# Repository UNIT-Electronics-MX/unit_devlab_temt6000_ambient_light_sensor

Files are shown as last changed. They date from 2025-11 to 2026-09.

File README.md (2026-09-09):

# DevLab: I2C TEMT6000 Ambient Light Sensor

The **DevLab I2C TEMT6000 Ambient Light Sensor** is a small ambient light sensor module that contains the **TEMT6000 phototransistor** and a **microcontroller**.This version has a **I2C interface** that allows the sensor signal to be captured, processed and accessed digitally from an I2C host, unlike a typical TEMT6000 module which only offers an analog output.

The module also includes a dedicated header for direct access to the **raw sensor signal** allowing the TEMT6000 output to be used directly for analog measurements, testing, characterization or custom signal processing. The board has three I2C connections, which makes it easy to integrate with other DevLab modules and I2C based systems.

<div align="center">

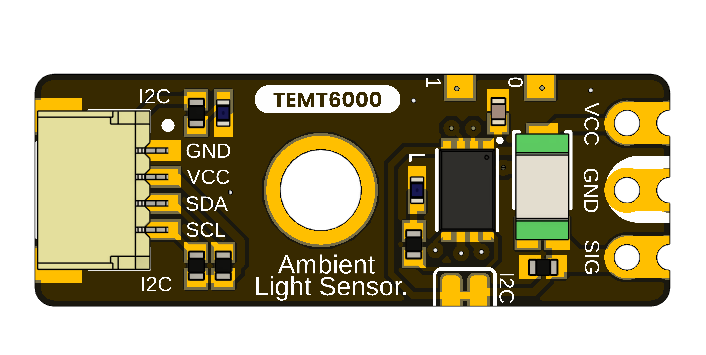
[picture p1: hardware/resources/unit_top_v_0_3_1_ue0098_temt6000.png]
DevLab I2C TEMT6000 Ambient Light Sensor
  

</div>

<div align="center">

### Quick Setup

[](https://wiki.uelectronics.com/wiki/devlab-temt6000-ambient-light-sensor)
[](https://github.com/UNIT-Electronics-MX/unit_devlab_temt6000_ambient_light_sensor/blob/main/hardware/unit_datasheet_v_1_0_0_ue0098_temt6000_ambient_light_sensor_en.pd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)
[](https://uelectronics.com/)
[](https://github.com/UNIT-Electronics-MX/unit_devlab_temt6000_ambient_light_sensor/tree/main/software)

</div>

## Overview

| Feature | Description |
|---|---|
| Sensor | TEMT6000 Ambient Light Sensor |
| Sensor Type | Ambient light phototransistor |
| Onboard MCU | 32-bit Arm Cortex-M0+ |
| Main Interface | I2C |
| Raw Signal Access | Direct sensor signal available through dedicated header |
| I2C Connectivity | 3 I2C connectors |
| Status Indicators | Power and user/status LEDs |
| Debug / Test | Dedicated test points |
| Module Function | Ambient light acquisition and I2C sensor interface |

## How It Works

The **TEMT6000** phototransistor generates a signal according to the incident ambient light level.

This signal is connected directly to the onboard **microcontroller**, which can acquire and process the sensor output and make the resulting information available through the **I2C interface**.

The board also exposes the sensor signal through the **RAW Signal Header**, allowing direct access to the unprocessed TEMT6000 output independently of the I2C interface.

This architecture provides two ways to work with the sensor:

- **I2C interface:** Easy digital integration with microcontrollers and other I2C systems.
- **RAW signal:** Direct access to the sensor output for analog measurements, testing, or custom processing.

## Use Cases

- Ambient light monitoring.
- Automatic display brightness adjustment.
- Smart lighting systems.
- Home and industrial automation.
- IoT environmental monitoring.
- Light-level data logging.
- Educational and prototyping applications.
- Sensor characterization using the RAW signal output.
- Integration into I2C sensor networks.

## Resources

- [Schematic Diagram](https://github.com/UNIT-Electronics-MX/unit_devlab_temt6000_ambient_light_sensor/blob/main/hardware/unit_sch_v_2_0_0_ue0098_temt6000.pdf)

- [Pinout Diagram](https://github.com/UNIT-Electronics-MX/unit_devlab_temt6000_ambient_light_sensor/blob/main/hardware/unit_pinout_v_0_0_2_ue0098_temt6000_ambient_light_sensor_en.pdf)

- [Datasheet](https://github.com/UNIT-Electronics-MX/unit_devlab_temt6000_ambient_light_sensor/blob/main/hardware/unit_datasheet_v_1_0_0_ue0098_temt6000_ambient_light_sensor_en.pd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)

## License

All hardware and documentation in this project are licensed under the **MIT License**.

Please refer to [`LICENSE.md`](LICENSE.md) for full terms.

<div align="center">

  <sub>Developed by UNIT Electronics</sub>

</div>

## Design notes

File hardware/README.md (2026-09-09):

# Hardware

<div align="center">

<a href="./unit_sch_v_2_0_0_ue0098_temt6000.pdf">
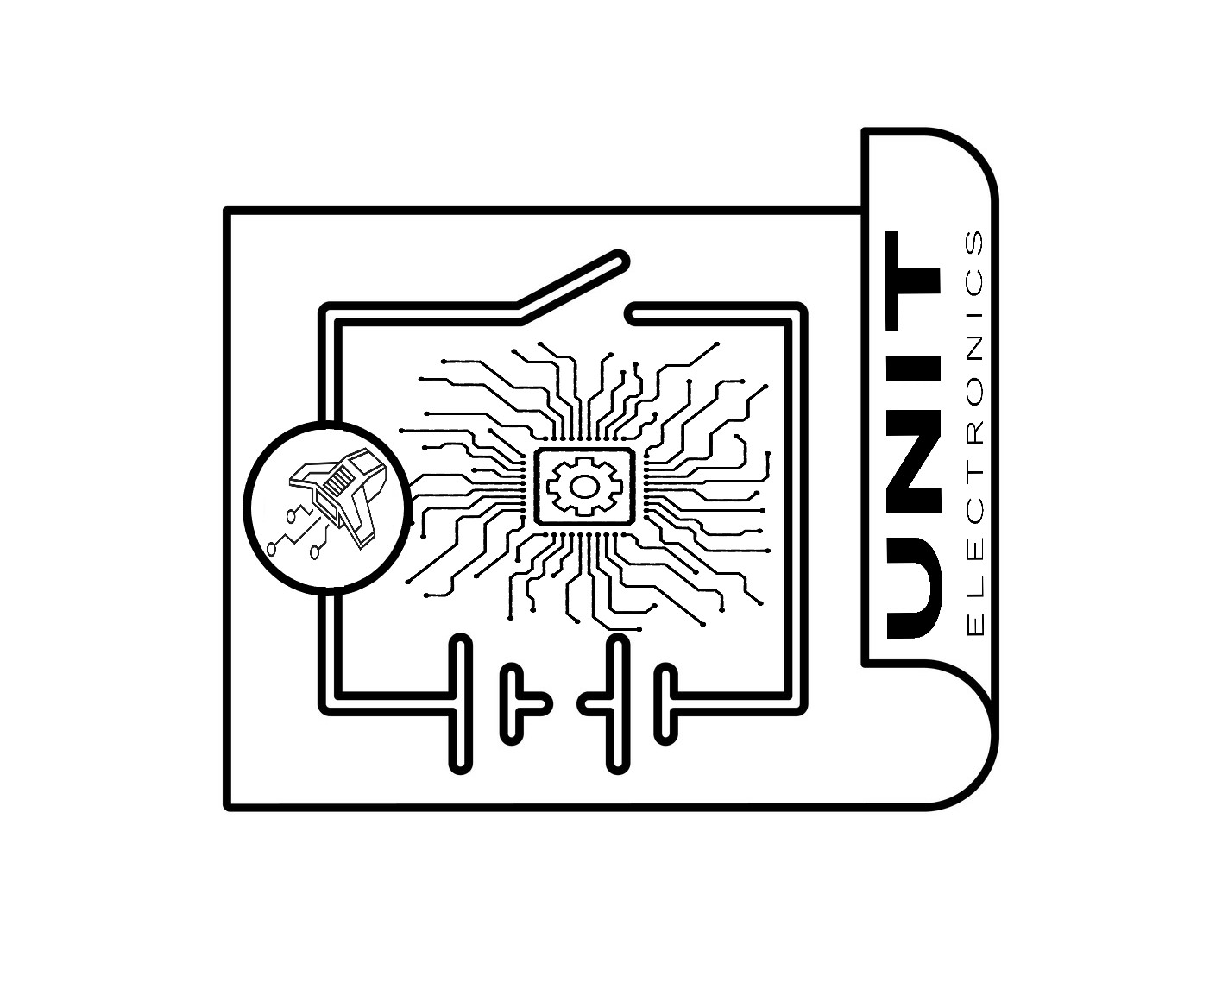
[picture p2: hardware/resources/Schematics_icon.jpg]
Schematics
  
  <br/>Schematics
</a>

</div>

---

## Key Technical Specifications

### Connectivity

<div align="center">

| Interface | Details |
|---|---|
| **Primary Interface** | I2C |
| **Sensor Interface** | TEMT6000 analog signal |
| **Raw Signal Access** | Dedicated RAW Signal Header |
| **I2C Connectors** | 3 × JST 4-pin, 1.0 mm pitch |
| **I2C Lines** | SDA, SCL |
| **Onboard MCU** | PY32F003L24D6TR |
| **I2C Pull-ups** | 10 kΩ |
| **Status Indicators** | Power LED and User LED |
| **Debug / Test** | Dedicated test points |

</div>

## Technical Specifications

The UE0098 integrates a **TEMT6000 ambient light sensor** with a
**microcontroller**, which acts as the interface between
the sensor signal and the I2C bus.

The TEMT6000 output is available for
signal acquisition and processing. The same sensor signal is also
exposed through a dedicated **RAW Signal Header**, allowing direct access
for measurement, testing, characterization, or external processing.

### I2C Interface

<div align="center">

| Signal | Type | Description |
|:---:|---|---|
| VCC | Power | Module power supply |
| GND | Power | Ground reference |
| SDA | I/O | I2C serial data |
| SCL | Input | I2C serial clock |

</div>

The board provides **three I2C connectors** connected to the same bus,
allowing convenient integration with other compatible I2C modules.

### RAW Signal Header

<div align="center">

| Signal | Type | Description |
|:---:|---|---|
| VCC | Power | Module supply voltage |
| GND | Power | Ground reference |
| SIGNAL | Analog | Direct TEMT6000 sensor signal |

</div>

> **Note:** The RAW Signal Header provides direct access to the TEMT6000
> sensor signal independently of the I2C interface.

## TEMT6000 Electrical Characteristics

The following characteristics correspond to the **TEMT6000 sensor**
itself and should not be interpreted as electrical limits for the
complete UE0098 module.

<div align="center">

| Symbol | Description | Min | Typ | Max | Unit |
|---|---|-----|-----|-----|---|
| V_CEO | Collector-emitter voltage | - | - | 6 | V |
| I_C | Collector current | - | - | 20 | mA |
| V_ECO | Emitter-collector voltage | - | - | 1.5 | V |
| P_V | Power dissipation | - | - | 100 | mW |
| φ | Angle of half sensitivity | - | ±60 | - | deg |
| λ_P | Wavelength of peak sensitivity | - | 570 | - | nm |
| λ_0.5 | Spectral bandwidth range | 440 | - | 800 | nm |

</div>

> **Note:** Refer to the Vishay TEMT6000 datasheet for complete sensor
> electrical and optical characteristics.

## Pinout

<div align="center">

<a href="./unit_pinout_v_3_1_0_ue0098_temt6000_ambient_light_sensor_en.pdf">
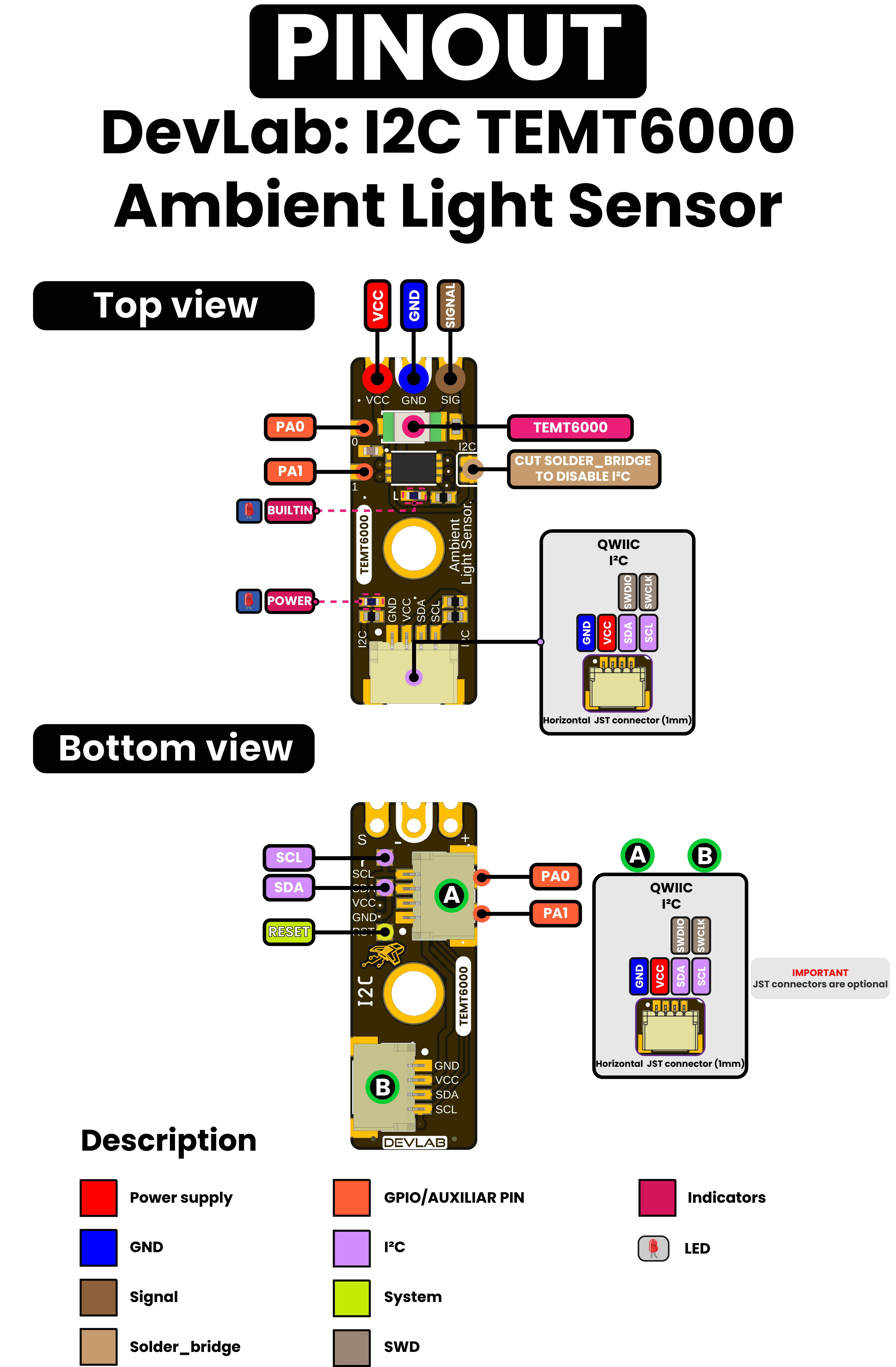
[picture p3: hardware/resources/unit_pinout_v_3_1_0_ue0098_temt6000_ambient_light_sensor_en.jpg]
  
  <br/>Pinout
</a>

<br/><br/>

</div>

### Pinout Details

#### I2C Connectors

<div align="center">

| Pin Label | Function | Description |
|---|---|---|
| VCC | Power Supply | Module power supply |
| GND | Ground | Common ground reference |
| SDA | I2C Data | Serial data line |
| SCL | I2C Clock | Serial clock line |

</div>

#### RAW Signal Header

<div align="center">

| Pin Label | Function | Description |
|---|---|---|
| VCC | Power Supply | Module power supply |
| GND | Ground | Common ground reference |
| SIGNAL | Raw Sensor Signal | Direct TEMT6000 output signal |

</div>

## Topology

<div align="center">

<a href="./resources/unit_topology_v_3_1_0_ue0098_temt6000_ambient_light_sensor.png">
  
  <br/>Topology
</a>

| Ref. | Description |
|---|---|
| TEMT6000 | Ambient Light Sensor |
| IC1 | PY32F003L24D6TR I2C Driver / |
| J1, J3, J4 | I2C JST 4-pin, 1.0 mm pitch connectors |
| J2 | RAW Signal Header |
| PWR | Power status LED |
| USR_LED | User / status LED |
| TP | Test points |

</div>

## Hardware Architecture

The module uses the following signal architecture:

**TEMT6000 → Raw Sensor Signal → microcontroller → I2C**

The TEMT6000 generates an analog signal according to the incident light
level. This signal is acquired by the onboard PY32F003,
which can process the sensor information and expose it through the I2C
interface.

In parallel, the unprocessed sensor signal remains available through the
**RAW Signal Header**:

**TEMT6000 → RAW Signal Header**

This architecture allows the module to be used both as an I2C ambient
light sensor and as a platform for direct access to the TEMT6000 signal.

## Dimensions

<div align="center">

<a href="./resources/unit_dimensions_v_3_1_0_ue0098_temt6000_ambient_light_sensor.png">
  
  <br/>Dimensions
</a>

</div>

## Reference

- [TEMT6000 Datasheet](https://www.vishay.com/docs/84374/temt6000.pdf)

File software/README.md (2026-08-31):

# Using the UNIT ATOM TEMT6000

UNIT Electronics creates and develops the DevLab board ecosystem, and this
product belongs to its Atom family. Hardware V0.3.1 provides two development
paths: Qwiic I2C through its onboard PY32F003 controller and direct analog observation
through `SIG`.

## I2C bring-up

Use a current-limited 3.3 V or 5 V supply and connect `GND`, `VCC`, `SDA`, and
`SCL` in the released pinout orientation. At 5 V, the host must tolerate the
actual I2C pull-up voltage or use a level shifter. Use 7-bit addressing and an I2C clock
from 100 kHz through 400 kHz. The repository includes low-level bus scanners:

The normal function of `PA10`/`PB6` is `SDA`/`SCL`. Their factory-only
`SWDIO`/`SWCLK` functions use the same physical pins, not a separate port, and
must never be driven while the I2C bus is active.

- [`examples/i2c/cpp_examples/i2c_scanner/i2c_scanner.ino`](examples/i2c/cpp_examples/i2c_scanner/i2c_scanner.ino)
  for C++ with the Arduino framework;
- [`examples/i2c/micropython/i2c_scan.py`](examples/i2c/micropython/i2c_scan.py) for
  MicroPython.

It also includes DDP measurement clients:

- [`examples/i2c/cpp_examples/ddp_temt6000/ddp_temt6000.ino`](examples/i2c/cpp_examples/ddp_temt6000/ddp_temt6000.ino)
  for C++ with the Arduino framework, using the canonical
  [`DevLabDDP`](https://github.com/UNIT-Electronics-Labs/unit_devlab_ddp_library)
  library;
- [`examples/i2c/micropython/ddp_temt6000.py`](examples/i2c/micropython/ddp_temt6000.py)
  for MicroPython, using the reusable
  [`devlab_ddp.py`](examples/i2c/micropython/lib/devlab_ddp.py) module.

The example tree is separated by interface (`i2c` or `adc`) and then by
language. See [`examples/README.md`](examples/README.md) for the selected
end-user examples and dependencies.

Both clients start with factory address `0x20`, can scan valid 7-bit addresses,
execute the mandatory DDP discovery sequence, accept only Device ID `0x0102`,
inspect capabilities at runtime, and then read the TEMT6000 sample. The command
is `TEMT6000_RAW` (`0x80`),
which returns a 12-bit ADC code (`0` to `4095`) in an unsigned 16-bit
little-endian response. The same published `PA2` sample is available through
common `READ_ADC0` (`0x60`).

The controller publishes an internally averaged ADC value approximately every 20 ms.
The persistent averaging window accepts 1, 4, 8, 16, or 24 samples; clients
read the current value before writing it. DDP address commands `0x20..0x24`
report, change, restore, and describe the active 7-bit address. Address and
averaging mutation are disabled by default in the examples.

`PB5/BUILTIN` uses `RELAY_OFF/ON/TOGGLE` (`0xA0..0xA2`), not the unsupported
digital-output commands. See [`protocol/README.md`](protocol/README.md) for the
exact controller command profile, staged acknowledgements, timing, and limitations.

For MicroPython installation and API details, see
[`examples/i2c/micropython/README.md`](examples/i2c/micropython/README.md). Copy
`devlab_ddp.py` to the host's `/lib` directory before running the DDP example.
The repository's ESP32 and MicroPython I2C examples use GPIO6 for SDA and GPIO7
for SCL.

## Direct analog bring-up

Connect the direct contacts while unpowered:

| Module | Host | Note |
|---|---|---|
| `GND` | Ground | Common reference |
| `VCC` | Module supply | 3.3 V or 5 V nominal; controller upper operating limit is 5.5 V |
| `SIG` | High-impedance ADC input | Signal is referenced to `VCC`; verify range before connecting a lower-voltage ADC |

- [`examples/adc/cpp_examples/light_sensor/light_sensor.ino`](examples/adc/cpp_examples/light_sensor/light_sensor.ino)
  reports averaged
  ADC code and voltage.
- [`examples/adc/micropython/light_sensor.py`](examples/adc/micropython/light_sensor.py)
  adds averaging and voltage conversion.

Set the ADC pin, resolution, and full-scale voltage for the host. The examples
do not convert to lux because the only schematic in the repository applies to
legacy V0.0.1 hardware; the V0.3.1 analog transfer needs release and validation.

## I2C disable bridge

Do not cut the bridge as a first troubleshooting step. Verify power, connector
orientation, SDA/SCL continuity, pull-ups, and bus ownership first. If the
current assembly must be isolated for analog-only testing, remove power and
document/inspect the rework carefully.

## Troubleshooting

| Symptom | Check |
|---|---|
| No I2C address | Supply and bus-logic compatibility, ground, connector population/orientation, SDA/SCL, intact bridge |
| Bus held low | Cable reversal, unpowered device, pull-ups, or unintended external drive on shared service lines |
| Address found but rejected | Confirm DDP protocol major 1 and Device ID `0x0102`; check for another device at that address |
| DDP device found but read fails | Confirm `ANALOG_INPUT`/`SENSOR_DATA`, 5 ms processing delay, exact response length, and command/STOP/read sequence |
| Analog always zero/full scale | ADC pin/range, supply, optical path, current-board transfer |
| Noisy analog value | Cable length, averaging, acquisition time, reference and supply noise |

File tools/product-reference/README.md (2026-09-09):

# Product Reference build

The UNIT ATOM TEMT6000 Product Reference source is maintained in Markdown under
`chapters/`. Document metadata and chapter order are defined in `book.yml`.
Version 1.1.0 is based on the V0.3.1 board images, V3.1.0 pinout, topology and
dimensions, current V2.0.0 schematic, a Vishay TEMT6000X01 datasheet used only
as a comparative reference, DevLab Device Protocol v1.0, and the repository
examples. The reference datasheet does not establish the exact orderable part
fitted to the module.

The Product Reference documents the current PY32F003 firmware profile: factory
address `0x20`, internal HSI operation at up to 24 MHz without an external
oscillator, DDP identity `0x0102`, versions 1.0, capabilities
`0x000001B9`, command timing, persistent configuration, ADC averaging, and the
`TEMT6000_RAW` (`0x80`) 12-bit response. It keeps the current-revision
schematic and complete module electrical limits as open qualification
requirements.

## Local validation build

Requirements:

- Pandoc
- WeasyPrint, Google Chrome, or Chromium

Run from the repository root and direct validation output outside the
repository:

```bash
./tools/product-reference/build.sh /tmp/atom-temt6000-product-reference
```

The build produces:

```text
unit_product_reference_v_1_1_0_atom_temt6000_ambient_light_sensor.md
unit_product_reference_v_1_1_0_atom_temt6000_ambient_light_sensor.docx
unit_product_reference_v_1_1_0_atom_temt6000_ambient_light_sensor.html
unit_product_reference_v_1_1_0_atom_temt6000_ambient_light_sensor.pdf
```

GitHub Actions publishes the PDF and DOCX under `docs/hardware/`. Do not edit
generated documents or `docs/` manually.

The Markdown chapters are the source of truth. Module values and mappings must
come from controlled technical references. The V0.3.1 module provides three
I2C connection positions on the same bus—one populated by default and two
optional horizontal positions—plus separate direct analog access through the
`VCC`/`GND`/`SIG` header. Do not infer complete-module limits from a component
rating alone.

Known source inconsistencies and unspecified board-level values are listed in
Chapter 9.

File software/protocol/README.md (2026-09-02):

# UNIT ATOM TEMT6000 — controller DDP device profile

UNIT Electronics creates and develops the DevLab board ecosystem; this product
belongs to its Atom family. Hardware V0.3.1 communicates through **DevLab
Device Protocol (DDP) v1.0** over I2C. This profile describes the observable
behavior of the current controller firmware. Common command values come from the canonical
[`unit_devlab_ddp_library`](https://github.com/UNIT-Electronics-Labs/unit_devlab_ddp_library).

Repository implementations are the Arduino `DevLabDDP` client and the reusable
MicroPython [`devlab_ddp.py`](../examples/i2c/micropython/lib/devlab_ddp.py) module. Both use the
same command/STOP/read transaction model and identity sequence.

## Released runtime profile

| Field | Current value |
|---|---|
| DDP Device ID | `0x0102` (little-endian bytes `[0x02, 0x01]`) |
| Protocol version | 1.0 (major/minor bytes `[0x01, 0x00]`) |
| Firmware version | 1.0 (major/minor bytes `[0x01, 0x00]`) |
| Hardware version | 1.0 (major/minor bytes `[0x01, 0x00]`) |
| Capabilities | `0x000001B9` (little-endian bytes `[0xB9, 0x01, 0x00, 0x00]`) |
| Factory 7-bit address | `0x20` |
| Configurable address range | `0x08..0x77` |
| I2C clock | 100 kHz to 400 kHz; examples use 400 kHz |
| Controller | PY32F003, 32-bit Arm Cortex-M0+; 16 KB Flash, 2 KB SRAM; internal HSI at up to 24 MHz for this application; no external HSE oscillator |
| Controller supply-voltage guidance | 2.0–5.5 V; conservative range used until the exact fitted variant is confirmed |
| Controller bus pins | `PB6/SCL`, `PA10/SDA` |
| Command/parameter size | One byte per write transaction |
| Maximum prepared response | Four bytes |
| Processing delay before read | 2–5 ms; use 5 ms conservatively |
| Pending setter timeout | 250 ms |
| ADC format | 12-bit unsigned, `0..4095`, little-endian `uint16` |

The capability bitmap announces `I2C_CONFIG`, `ANALOG_INPUT`, `SENSOR_DATA`,
`RELAY`, `WATCHDOG`, and `PERSISTENT_CONFIG`. It does not announce digital I/O;
commands `READ_GPIO0/1` (`0x40/0x41`) and `WRITE_GPIO0/1` (`0x42/0x43`) are not
implemented.

### Meaning of byte `0x01`

`0x01` has no universal meaning in DDP; its meaning comes from the command,
response length, and field encoding. In this profile:

- as a command byte, `0x01` selects `GET_FIRMWARE_VERSION`;
- in version bytes `[0x01, 0x00]`, it is major version 1;
- in Device ID bytes `[0x02, 0x01]`, it is the high byte of little-endian
  `0x0102`;
- in capability bytes `[0xB9, 0x01, 0x00, 0x00]`, it is byte 1 of the
  little-endian bitmap `0x000001B9`;
- as the low nibble of a `RELAY_ON` acknowledgement, `0x1` means that driving
  `PB5/BUILTIN` HIGH was accepted; and
- as the `GET_I2C_STATUS` response, `0x01` means the active address was loaded
  from Flash.

Never interpret an isolated `0x01` without first identifying its command and
expected response format.

## Logical and physical mapping

| Logical resource | Physical resource | Implemented command |
|---|---|---|
| `ADC0` | TEMT6000 sampled on controller `PA2` | `READ_ADC0` (`0x60`) |
| TEMT6000 sensor data | Same published ADC sample | `TEMT6000_RAW` (`0x80`) |
| Relay-compatible actuator | Controller `PB5` / `BUILTIN` | `RELAY_OFF/ON/TOGGLE` (`0xA0..0xA2`) |
| `PA0`, `PA1` | Exposed reserved pads | No current application assignment |

`READ_ADC0` and `TEMT6000_RAW` return the same most recently published
sample. An I2C read does not start an ADC conversion. The historical `RELAY_*`
names control `PB5` and therefore the `BUILTIN` indicator on this product.

## I2C transaction model

This is a command protocol, not a memory-mapped register interface. A normal
read requires a STOP between command and response:

```text
host -> [SLA+W, command] -> STOP
wait 2..5 ms
host -> [SLA+R, exact documented response length] -> NACK + STOP
```

Do not send a command and its parameter in one write. Setters use two explicit
stages and packed compatibility acknowledgements:

```text
host -> [SLA+W, command] -> STOP
wait, then read one-byte initial ACK
host -> [SLA+W, value] -> STOP       (within 250 ms)
wait, then read one-byte final ACK
```

Validate the documented low nibble of each staged-operation acknowledgement;
never mask ADC data, addresses, versions, or averaging values. If a read is too
early or too long, transport padding can be `0xFF`, so clients must validate
length, identity, and value range.

## Mandatory discovery

| Order | Command | Value | Exact current response |
|---:|---|---:|---|
| 1 | `GET_PROTOCOL` | `0x04` | `[0x01, 0x00]` = major 1, minor 0 |
| 2 | `GET_DEVICE_ID` | `0x00` | `[0x02, 0x01]` = little-endian `0x0102` |
| 3 | `GET_FIRMWARE_VERSION` | `0x01` | `[0x01, 0x00]` = major 1, minor 0 |
| 4 | `GET_HARDWARE_VERSION` | `0x02` | `[0x01, 0x00]` = major 1, minor 0 |
| 5 | `GET_CAPABILITIES` | `0x03` | `[0xB9, 0x01, 0x00, 0x00]` = little-endian `0x000001B9` |

Cache identity after `begin()` rather than repeating all five reads before
every sample. Repeat discovery after reset, address change, or bus recovery.

## Implemented application commands

| Command | Code | Response/effect |
|---|---:|---|
| `READ_ADC0` | `0x60` | ADC `[LSB, MSB]` |
| `SET_ADC_AVERAGING` | `0x62` | Staged write; ACK low nibble `0xC` |
| `GET_ADC_AVERAGING` | `0x63` | `1`, `4`, `8`, `16`, or `24` |
| `TEMT6000_RAW` | `0x80` | Same ADC `[LSB, MSB]` as `0x60` |
| `RELAY_OFF` | `0xA0` | ACK low `0x0`; drives `PB5` low |
| `RELAY_ON` | `0xA1` | ACK low nibble `0x1` = `PB5` HIGH accepted |
| `RELAY_TOGGLE` | `0xA2` | ACK low `0x6`; non-blocking pulse |
| `SET_TOGGLE_TIME` | `0xA3` | Staged write `1..40`; ACK low `0x7` |
| `GET_TOGGLE_TIME` | `0xA4` | `1..40`, in units of 25 ms |

`READ_GPIO0/1`, `WRITE_GPIO0/1`, and `READ_ADC1` are not implemented and
return the packed unknown-command code with low nibble `0xB`.

## ADC acquisition and averaging

The controller updates its ADC sample in the background approximately every 20 ms
(about 50 samples/s). For each update it discards one conversion to settle the
sample-and-hold, takes one 12-bit conversion, updates a circular buffer, and
publishes `round(sum / valid_samples)`.

| Samples | Window | Fill time after change | Typical use |
|---:|---:|---:|---|
| 1 | 20 ms | 20 ms | Fast response |
| 4 | 80 ms | 80 ms | Low-latency control |
| 8 | 160 ms | 160 ms | UI and general automation |
| 16 | 320 ms | 320 ms | Stable ambient measurement |
| 24 | 480 ms | 480 ms | Maximum stability |

The factory averaging value is 1. `SET_ADC_AVERAGING` persists the selected
value in Flash, so read `GET_ADC_AVERAGING` first and write only when it needs
to change. Wait `N × 20 ms` for a fully refilled window. Do not poll faster than
20 ms expecting a new sample, and do not describe the raw average as lux.

## Address management

| Command | Code | Current behavior |
|---|---:|---|
| `GET_I2C_ADDR` | `0x20` | Active 7-bit address |
| `SET_I2C_ADDR` | `0x21` | Staged value `0x08..0x77`; ACK low `0xD`; saves Flash and resets automatically |
| `SAVE_CONFIG` | `0x22` | Returns `00`; idempotent because setters already persist |
| `RESET_FACTORY` | `0x23` | ACK low `0xE`; reset still required |
| `GET_I2C_STATUS` | `0x24` | `0x00` = factory/default; `0x01` = address loaded from Flash |

Before an address change, verify that the target is free. Read the initial ACK,
write the new value within 250 ms, wait about 100 ms for Flash, read the final
ACK at the old address, wait about 300 ms for reset, then verify protocol 1.x
and Device ID `0x0102` at the new address. If the final ACK is lost, probe the
new address once and then the old address rather than rewriting indefinitely.

Factory restoration keeps the old address active until reset:

```text
old: RESET_FACTORY (0x23) -> ACK low 0xE
old: RESET (0xF0) -> do not request a response
wait 300 ms
identify factory address 0x20
```

## Built-in indicator

`PB5/BUILTIN` uses the relay-compatible actuator block, not digital GPIO
output commands. A client can blink using `RELAY_ON`/`RELAY_OFF` with host
timing, or request a non-blocking pulse with `RELAY_TOGGLE`. Toggle time accepts
`1..40` units of 25 ms (25–1000 ms) and is persistent.

## Current firmware limitations

- `WATCHDOG` is announced, but `WATCHDOG_RESET` does not use an active hardware
  IWDG and must remain experimental/disabled by default.
- `GET_RESET_INFO` is not implemented; NRST support is incomplete.
- The internal error sentinel can appear as `0x0FFF`, indistinguishable from a
  legitimate full-scale ADC sample.
- Bus-BUSY recovery exists in firmware but is not called by the current main
  loop.
- There is no timestamp, sample counter, or calibrated lux output.
- The V0.3.1 schematic and complete module electrical limits remain pending.

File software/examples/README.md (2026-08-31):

# UNIT ATOM TEMT6000 examples

Choose the interface first. The `i2c/` examples use the module's DDP firmware;
the `adc/` examples read the separate direct `SIG` contact. They are kept in
different trees so wiring and host-pin assumptions are not mixed.

## Layout

```text
examples/
├── i2c/
│   ├── cpp_examples/
│   │   ├── ddp_temt6000/       normal DDP measurement client
│   │   └── i2c_scanner/        bus troubleshooting only
│   └── micropython/
│       ├── lib/devlab_ddp.py   reusable library; copy to the board's /lib
│       ├── ddp_temt6000.py     normal DDP measurement client
│       └── i2c_scan.py         bus troubleshooting only
└── adc/
    ├── cpp_examples/
    │   └── light_sensor/       direct SIG reading
    └── micropython/
        └── light_sensor.py     averaged direct SIG reading
```

## I2C — recommended interface

Start with `ddp_temt6000` for normal operation. Use `i2c_scanner` or
`i2c_scan.py` only when the module is not discovered.

| Language | Normal example | Diagnostic example |
|---|---|---|
| C++/Arduino framework | [`i2c/cpp_examples/ddp_temt6000`](i2c/cpp_examples/ddp_temt6000/ddp_temt6000.ino) | [`i2c/cpp_examples/i2c_scanner`](i2c/cpp_examples/i2c_scanner/i2c_scanner.ino) |
| MicroPython | [`i2c/micropython/ddp_temt6000.py`](i2c/micropython/ddp_temt6000.py) | [`i2c/micropython/i2c_scan.py`](i2c/micropython/i2c_scan.py) |

The ESP32 and MicroPython I2C examples use host GPIO6 for SDA and GPIO7 for
SCL. Generic Arduino targets fall back to the board's default `Wire` pins.
These are host pins, not the module's internal controller pins.

The C++ client requires the canonical
[`DevLabDDP`](https://github.com/UNIT-Electronics-Labs/unit_devlab_ddp_library)
library. For MicroPython, install
[`i2c/micropython/lib/devlab_ddp.py`](i2c/micropython/lib/devlab_ddp.py) in the
device's `/lib` directory; see the
[`i2c/micropython` guide](i2c/micropython/README.md).

## ADC — direct SIG only

Use this path only when the host is wired to the direct `SIG` contact instead
of using the DDP measurement client.

| Language | Example |
|---|---|
| C++/Arduino framework | [`adc/cpp_examples/light_sensor`](adc/cpp_examples/light_sensor/light_sensor.ino) |
| MicroPython | [`adc/micropython/light_sensor.py`](adc/micropython/light_sensor.py) |

Set the ADC-capable host pin and full-scale voltage for the selected board.
The examples report ADC code and voltage, not lux, because the V0.3.1 analog
transfer function still requires release and validation.

## Electrical note

The module supports nominal 3.3 V or 5 V operation. At 5 V, the host must
tolerate the actual I2C pull-up level or use a bidirectional level shifter.
`SDA/SCL` share their physical controller pins with the factory-only
`SWDIO/SWCLK` functions; user examples use I2C only.

See [`../protocol/README.md`](../protocol/README.md) for command timing,
response formats, capabilities, and address-change behavior.

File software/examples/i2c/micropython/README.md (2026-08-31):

# DevLab DDP for MicroPython

[`lib/devlab_ddp.py`](lib/devlab_ddp.py) is a reusable MicroPython master for DevLab
Device Protocol 1.0 over I2C. It mirrors the canonical Arduino transport rules:

- one command byte followed by STOP;
- a configurable processing delay before the response read;
- exact response lengths;
- little-endian decoding for Device ID, capabilities, and ADC data;
- mandatory protocol-major validation;
- Device ID discovery and matching;
- staged one-byte setters with packed acknowledgement validation; and
- collision-safe persistent I2C address changes.

## Install on a MicroPython board

Create `/lib` if it does not exist, then copy the module and example with
`mpremote`:

```bash
mpremote fs mkdir :/lib
mpremote fs cp software/examples/i2c/micropython/lib/devlab_ddp.py :/lib/devlab_ddp.py
mpremote fs cp software/examples/i2c/micropython/ddp_temt6000.py :/ddp_temt6000.py
```

The included I2C examples default to host GPIO6 for SDA and GPIO7 for SCL.
Edit `I2C_BUS`, `SDA_PIN`, and `SCL_PIN` only when the host board requires a
different mapping, then run:

```bash
mpremote run software/examples/i2c/micropython/ddp_temt6000.py
```

The module uses only the standard `machine.I2C` API. The host port must provide
`scan()`, `writeto()`, and `readfrom()` with STOP support.

## Minimal use

```python
from machine import I2C, Pin
from devlab_ddp import DEVICE_TEMT6000, Master, format_device_info

i2c = I2C(0, sda=Pin(6), scl=Pin(7), freq=400_000)
ddp = Master(i2c, expected_device_id=DEVICE_TEMT6000)
info = ddp.discover(preferred_address=0x20)

if info is None:
    raise OSError("TEMT6000 DDP device not found")

print(format_device_info(info, DEVICE_TEMT6000))
print(ddp.read_adc(info.address, channel=0, verify=False))
```

After discovery, `verify=False` avoids repeating the five identity reads before
every sample. Repeat discovery after reset, address change, or bus recovery.

## Main API

| Method | Purpose |
|---|---|
| `identify(address)` | Read protocol, Device ID, versions, and capabilities |
| `discover(preferred_address=None)` | Find the expected DDP device on the bus |
| `scan_ddp()` | Return every valid DDP device found |
| `read_command(address, command, length)` | Execute the DDP command/STOP/read transaction |
| `read_adc(address, channel)` | Read generic ADC0 or ADC1 |
| `read_gpio(address, channel)` | Read logical GPIO0 or GPIO1 |
| `get_adc_averaging(address)` | Read the persistent averaging window |
| `set_adc_averaging(address, samples)` | Apply a validated staged averaging write |
| `get_i2c_address(address)` | Read the active 7-bit address |
| `set_i2c_address(old, new)` | Check collision, persist the address, and rediscover |
| `relay_off/on/toggle(address)` | Execute the relay-compatible actuator commands |
| `set_toggle_time(address, units)` | Set `1..40` units of 25 ms |

Protocol constants, capability bits, Device IDs, response codes, exception
types, little-endian helpers, and `DeviceInfo` are exported by the module.

## Host-side tests

The tests use a scripted fake I2C bus and do not require hardware:

```bash
python3 -m unittest software/tests/test_devlab_ddp.py
```

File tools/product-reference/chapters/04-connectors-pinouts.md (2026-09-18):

## **4 Connectors & Pinouts**

The user-accessible interfaces are described below by module function. The
released documentation does not provide controlled contact numbers or a
mating-connector part number, so the signal order must be checked against the
connector orientation before producing a harness.

### **4.1 General Pinout** {.section-page}

| Connection group | Signals | Function |
|---|---|---|
| Direct sensor contacts | `VCC`, `GND`, `SIG` | Module power and direct access to the TEMT6000 analog signal |
| I2C connection positions | `GND`, `VCC`, `SDA`, `SCL` | Power and digital communication over the common I2C bus |
| Reserved expansion pads | Reserved | No current application assignment; electrical limits are not specified |

The PCB has three physical I2C connection positions. One connector is
populated by default, and two additional horizontal positions accept optional
4-pin, 1.00 mm-pitch JST/Qwiic-compatible connectors. All three positions are
connected to the same I2C bus.

### **4.2 Signal and I2C Connection Guide** {.page-break}

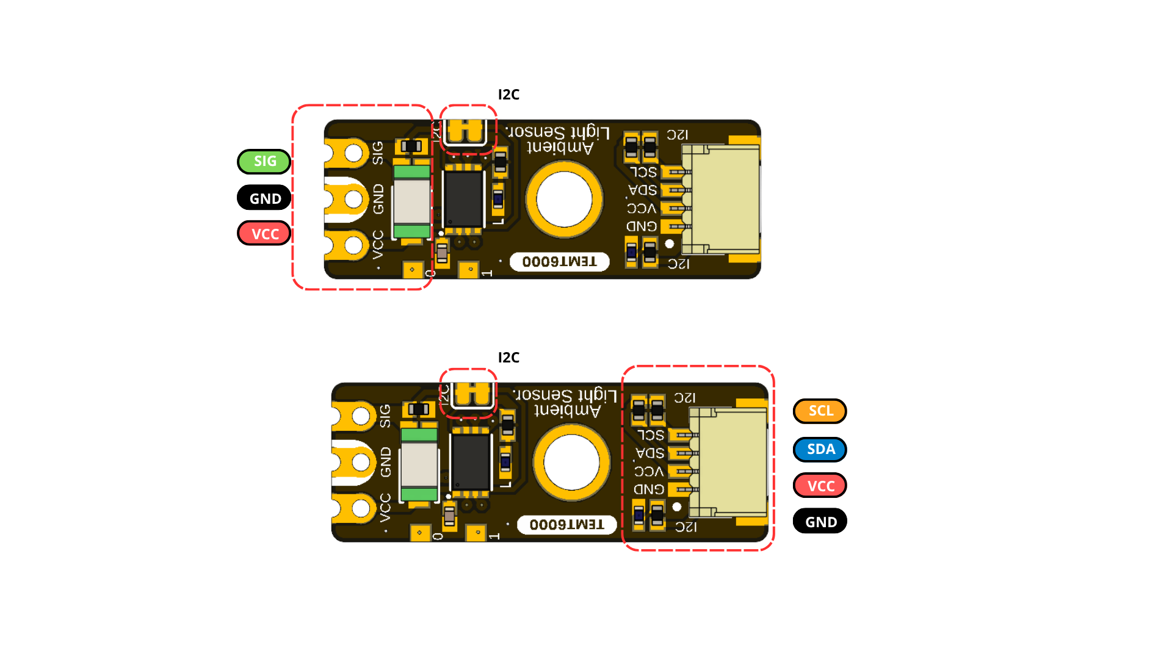
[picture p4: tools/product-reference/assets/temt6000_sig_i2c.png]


**Figure 4.1 — Direct analog and I2C connection groups.** The direct contacts
provide `SIG`, `GND`, and `VCC`; the populated I2C connector provides `SCL`,
`SDA`, `VCC`, and `GND`. Always follow the connector orientation shown on the
board.

### **4.3 Direct Sensor Contacts**

| Label | Type | Description |
|---|---|---|
| `VCC` | Power | Module supply; nominal 3.3 V or 5 V operation |
| `GND` | Power | Common power and signal reference |
| `SIG` / `SIGNAL` | Analog | Direct light-dependent sensor signal; current transfer function unspecified |

These three contacts are shown at the end opposite the populated I2C
connector. `SIG` provides direct access to the TEMT6000 analog signal; it is
not a separate specialized communication port.

### **4.4 I2C Connection Positions** {.section-page}

| Signal | Type | Description |
|---|---|---|
| `GND` | Power | Common return |
| `VCC` | Power | I2C peripheral supply; nominal 3.3 V or 5 V |
| `SDA` | Bidirectional I2C data | Host must tolerate the actual bus pull-up voltage |
| `SCL` | I2C clock | Supported at 100 kHz to 400 kHz |

The two optional horizontal I2C connector positions use the same signal set
and 1.00 mm pitch as the populated connector. Because all three positions are
physical access points to the same bus, an optional connector may be used for
an alternate cable orientation or bus continuation. Account for the loading
and pull-ups of every attached device.

The I2C connection points share signals with the controller's factory
programming and debugging interface. These functions are mutually exclusive,
and there is no separate user-accessible SWD connector.

### **4.5 Auxiliary and Factory Service Functions**

| Function | Documented role | Qualification status |
|---|---|---|
| Reserved expansion pad 1 | Reserved connection | No current application assignment; electrical limits unspecified |
| Reserved expansion pad 2 | Reserved connection | No current application assignment; electrical limits unspecified |
| Controller reset | Factory service function | Manufacturer programming and factory diagnostics only |

Programming, debugging, and reset are intended primarily for development, manufacturing, and service purposes. Currently, user firmware programming is not supported or documented. During programming or diagnostics, I2C must be inactive and other bus devices must be isolated from the shared signals.

### **4.6 Indicators and I2C Bridge**

The module provides a power indicator, a firmware-controlled built-in status indicator, and a normally closed solder bridge that connects the sensor’s raw output signal to the controller ADC input. Opening the bridge isolates the raw sensor signal from the ADC, and the connection can be restored by re-soldering the bridge. The controller ADC input used for sensor acquisition is internal to the module and is not an additional external contact.

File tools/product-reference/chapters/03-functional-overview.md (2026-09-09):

## **3 Functional Overview**

The UNIT ATOM TEMT6000 combines an ambient-light phototransistor with an
onboard controller. The module provides two ways to observe light level:
digital readings over I2C and direct access to the analog sensor signal at
`SIG`.

The TEMT6000 itself is an analog device. The onboard controller samples its
output, applies the selected averaging, and provides the latest raw reading
through DevLab Device Protocol (DDP) v1.0.

### **3.1 Functional Block Diagram** {.section-page}

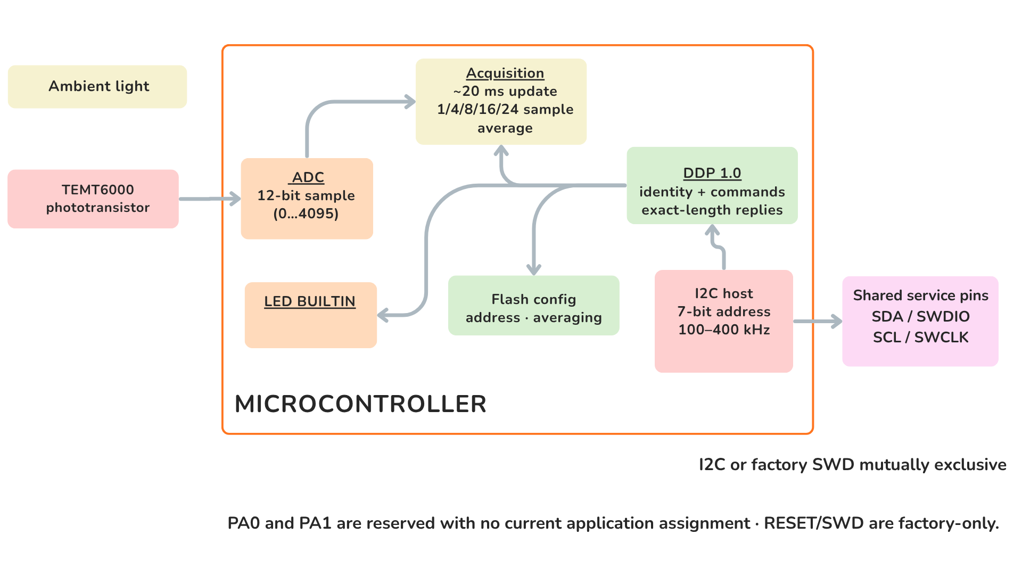
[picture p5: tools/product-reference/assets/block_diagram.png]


**Figure 3.1 — Functional signal and control paths.** Ambient light changes the
TEMT6000 output. The signal is available at `SIG` and is also acquired by the
controller ADC for access over I2C.

### **3.2 Operating Modes**

| Mode | Connection | User-visible result |
|---|---|---|
| Digital I2C | `VCC`, `GND`, `SDA`, and `SCL` | Averaged 12-bit raw light reading through DDP |
| Direct analog | `VCC`, `GND`, and `SIG` | Light-dependent voltage for a host ADC or measurement instrument |

Both modes observe the same sensor path. An I2C read returns the latest
available sample; it does not trigger a new light measurement. The direct
analog output may be used independently for development, comparison, or
application-specific calibration.

### **3.3 Digital Light Measurement** {.page-break}

The onboard ADC produces an unsigned 12-bit value. A higher value represents a
higher sensor output under the actual supply, optical, and mechanical
conditions.

| Measurement property | Value |
|---|---:|
| ADC resolution | 12 bits |
| Raw output range | `0..4095` |
| Response format | Two bytes, `[LSB, MSB]` |
| Update interval | Approximately 20 ms |
| Selectable averaging | 1, 4, 8, 16, or 24 samples |

The averaging setting controls the balance between response speed and
stability:

| Samples | Approximate time for a completely new average | Typical use |
|---:|---:|---|
| 1 | 20 ms | Fast changes |
| 4 | 80 ms | Low-latency smoothing |
| 8 | 160 ms | General monitoring |
| 16 | 320 ms | Stable ambient-light monitoring |
| 24 | 480 ms | Maximum available smoothing |

The result is a relative ADC reading, not a calibrated lux measurement.
Quantitative lux measurements require calibration in the final enclosure and
optical arrangement.

### **3.4 I2C Communication Model** {.page-break}

The I2C host always initiates communication. The 7-bit I2C address selects the
module, while the one-byte DDP selector identifies the requested function.
These are independent values.

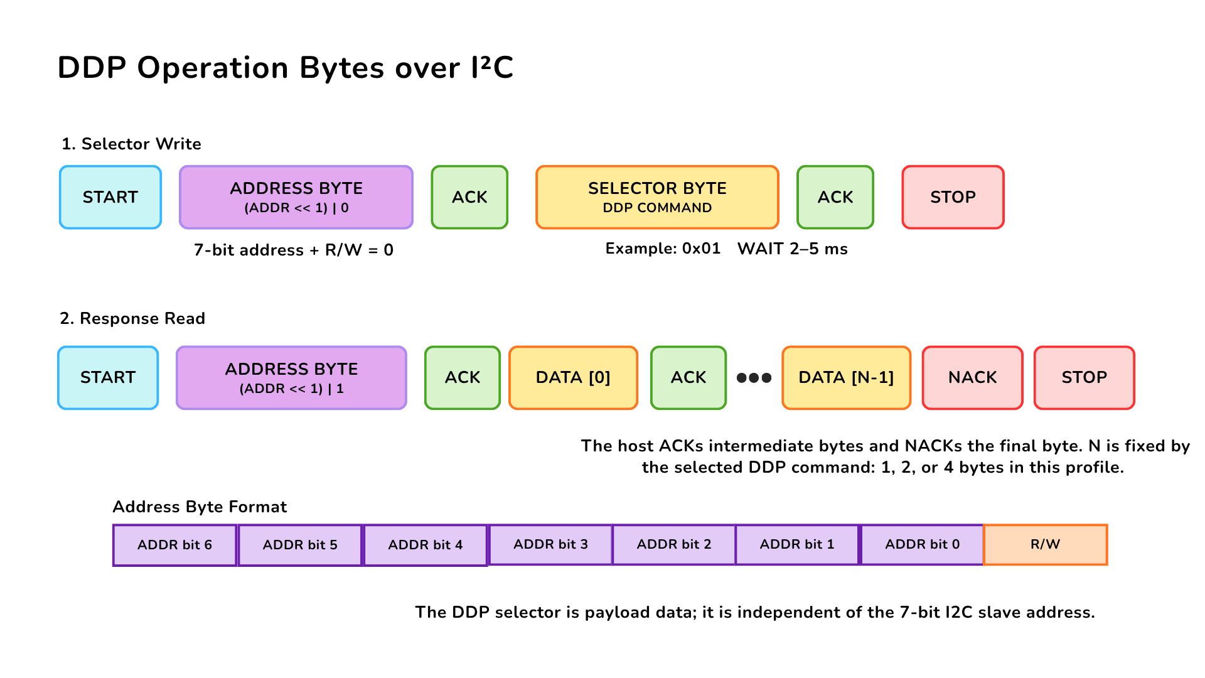
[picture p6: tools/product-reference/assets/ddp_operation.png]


**Figure 3.2 — DDP command and response over I2C.** The host writes one DDP
selector, issues STOP, waits 2–5 ms, and then reads the documented number of
response bytes. The host acknowledges intermediate bytes and sends NACK after
the final byte.

| Communication property | Value |
|---|---|
| Factory 7-bit address | `0x20` |
| Configurable address range | `0x08..0x77` |
| I2C clock | 100 kHz to 400 kHz |
| Delay before response read | 2–5 ms; use 5 ms conservatively |
| Byte order for multi-byte values | Little endian |
| Supported response lengths | 1, 2, or 4 bytes, depending on the selected function |

Pass `0x20` directly to an I2C library. Values `0x40` and `0x41` are the
shifted write/read address bytes visible on the bus, not the 7-bit address used
by typical host APIs.

### **3.5 User-Accessible DDP Functions** {.section-page}

| User function | DDP selector | Result |
|---|---:|---|
| Identify the module | `0x00` | Device ID `0x0102` |
| Read protocol version | `0x04` | DDP version 1.0 |
| Read active I2C address | `0x20` | Current 7-bit address |
| Change I2C address | `0x21` | Stores and applies a new address in the valid range |
| Restore factory configuration | `0x23` | Restores default configuration; reset required |
| Read ambient-light data | `0x60` or `0x80` | Latest two-byte 12-bit raw sample |
| Set ADC averaging | `0x62` | Selects 1, 4, 8, 16, or 24 samples |
| Read ADC averaging | `0x63` | Returns the active averaging setting |
| Turn `BUILTIN` off/on | `0xA0` / `0xA1` | Drives the built-in indicator LOW/HIGH |
| Pulse `BUILTIN` | `0xA2` | Starts a non-blocking timed pulse |
| Set/read pulse time | `0xA3` / `0xA4` | Uses 1–40 units of 25 ms |

The I2C address, averaging selection, and pulse duration are retained after a
power cycle. Changing a stored value should be an occasional configuration
operation rather than part of the normal measurement loop.

Detailed transaction handling is already implemented by the maintained C++
and MicroPython examples listed in Chapter 8.

### **3.6 Built-In Indicator**

The built-in status indicator is controlled through the DDP actuator
functions. The shared DDP command names contain `RELAY`, but this product uses
them for the built-in indicator and does not provide an electromechanical
relay output.

The pulse duration is configurable from 25 ms to 1000 ms in 25 ms steps. A
timed pulse runs without interrupting light measurements or I2C communication.

### **3.7 Physical Interface Notes** {.section-page}

The `SIG` contact provides direct access to the analog sensor path. Its
complete board-level transfer function, source impedance, and guaranteed
output range are not specified for the current revision. Use a high-impedance
input and verify the actual range before connecting it to a lower-voltage ADC.

The PCB provides three I2C connection positions carrying `GND`, `VCC`, `SDA`,
and `SCL`: one connector is populated by default and two horizontal positions
are provided for optional 4-pin, 1.00 mm-pitch JST/Qwiic-compatible
connectors. All three positions access the same I2C bus.

The I2C connection points share signals with the controller's factory
programming and debugging interface; there is no separate user-accessible SWD
connector. Programming, debug, and reset functions are reserved for
manufacturer programming and factory diagnostics, not user firmware
replacement.

Two expansion pads are reserved and have no current user function. The I2C
disable bridge is intended for applications that require the analog path
without active I2C operation; remove power before cutting or restoring it.

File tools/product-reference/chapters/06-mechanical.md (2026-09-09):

## **6 Mechanical Information**

The current mechanical drawing defines the board outline and the dimensions
shown below. Dimensions are in millimetres.

### **6.1 Board Dimensions** {.section-page}



**Figure 6.1 — Board dimensions.**

The drawing specifies a 27 mm × 10 mm board outline and a 3 mm mounting hole.
It also shows the hole centerline 5 mm from the side edge and 10.8 mm from the
connector-end edge. Use the drawing itself as the dimensional reference; do
not derive additional dimensions by scaling the image.

### **6.2 Integration Clearances** {.section-page}

Leave optical clearance around the transparent TEMT6000 sensor package and its
field of view. Provide connector insertion and cable bend clearance at the
populated I2C connector and at any optional connector position that will be
assembled. Keep conductive fasteners away from contacts and factory service
points, and avoid enclosure features that shadow the sensor or indicators.

### **6.3 Mechanical Data Not Specified**

- Board thickness, dimensional tolerances, and finished mass
- Unannotated feature coordinates and edge clearances
- Optional connector population variants and mating-part numbers
- Connector insertion envelope, retention force, and cable bend radius
- Maximum top- and bottom-side component heights
- Optical axis, keep-out cone, and enclosure-window specification
- Reserved expansion-pad and factory service-point coordinates

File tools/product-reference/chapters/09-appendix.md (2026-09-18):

## **9 Appendix**

### **9.1 Current V2.0.0 Schematic** {.section-page}

The current schematic is documented in
`hardware/unit_sch_v_2_0_0_ue0098_temt6000.pdf`. It documents the
controller-based V0.3.1 board, including the reference controller, TEMT6000
analog stage, I2C interfaces, status indicators, test points, and optional
connectors.

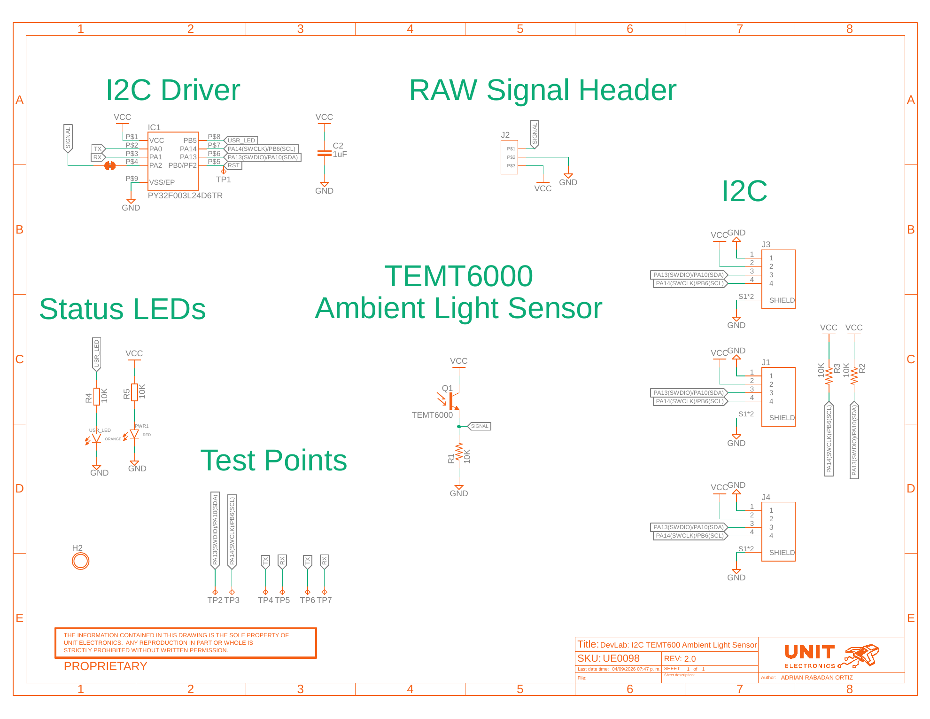
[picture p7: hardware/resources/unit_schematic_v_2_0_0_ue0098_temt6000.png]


**Figure 9.1 — Current V2.0.0 electrical schematic.**

The sensor signal uses a 10 kΩ resistor (`R1`) to ground and is routed to the
controller ADC input and the external `VCC`/`GND`/`SIG` header. As a
first-order estimate outside saturation, `VSIGNAL ≈ IPCE × 10 kΩ`; this is
not a calibrated or guaranteed conversion to lux.

The I2C `SDA` and `SCL` signals are available at three physical connection
positions: one connector populated by default and two optional horizontal
positions. These signals are shared with the controller's factory programming
and debugging interface; there is no separate user-accessible SWD connector.

### **9.2 Document Control** {.section-page}

| Field | Value |
|---|---|
| Product | UNIT ATOM TEMT6000 Ambient Light Sensor |
| Product hierarchy | UNIT Electronics → DevLab board ecosystem → Atom family |
| Manufacturer Part Number (MPN) | UE0098 |
| Current board artwork | V0.3.1 |
| Current pinout, topology, and dimensions | V3.1.0 |
| Available schematic | Current V2.0.0 |
| Product Reference | Version 1.1.0 |
| Publication date | 2026-08-31 |
| Interfaces | Three I2C connection positions on one bus; `VCC`/`GND`/`SIG` header; reserved expansion pads; shared factory programming/debug signals |

### **9.3 Technical Data Not Specified in This Revision**

- Complete-module absolute-maximum ratings and current consumption
- I2C pull-up values and validated bus-loading limits
- Direct `SIG` output range, loading characteristics, and ADC guidance
- Mechanical tolerances, board thickness, component heights, and finished mass
- Module-level optical, electrical, environmental, and EMC characterization

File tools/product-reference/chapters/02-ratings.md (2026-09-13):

## **2 Ratings**

This chapter summarizes the electrical operating conditions and interface
characteristics relevant to integrating the UNIT ATOM TEMT6000. It covers the
module supply, I2C operation, analog sensor path, controller capabilities, and
ambient-light sensor characteristics. Use these ratings to select a compatible
power source and host interface and to identify the electrical characteristics
that require application-specific verification.

### **2.1 Recommended Operating Conditions** {.section-page}

| Symbol | Description | Min. | Typ. | Max. | Unit |
|---|---|---:|---:|---:|---|
| `VCC` | Module supply voltage | — | 3.3 or 5 | — | V |
| `VI2C` | I2C logic-high and pull-up voltage | — | `VCC` | — | V |
| `fSCL` | I2C clock frequency | 100 | — | 400 | kHz |
| `VSIG` | Direct analog `SIG` voltage range | — | Not specified | — | V |
| `ICC` | Module supply current | — | Not specified | — | mA |
| `TA` | Module ambient operating temperature | Not specified | — | Not specified | °C |

The `VCC` values are the supported nominal operating points; they are not
complete-module absolute maximum ratings. The validated continuous supply
range around each nominal point is not specified.

Use a current-limited source during initial bring-up. The I2C pull-ups follow
the module supply, so the host must tolerate the actual bus voltage. When the
module operates at 5 V with a 3.3 V host, bidirectional level translation may
be required.

The direct `SIG` range requires analog-stage verification and measurement.
Module current consumption must include the controller, indicators, pull-ups,
and sensor load. The complete-module ambient-temperature range has not been
qualified. I2C pull-up resistance, bus capacitance, and complete-module
absolute maximum ratings are also not specified.

### **2.2 Digital Interface and Firmware Characteristics**

| Parameter | Value | Description |
|---|---:|---|
| I2C addressing | 7-bit slave | Valid configurable addresses are `0x08..0x77` |
| Factory I2C address | `0x20` (7-bit) | Pass `0x20` directly to the host I2C library; `0x40` is the 8-bit write address, not the device address |
| Device protocol | DDP v1.0 | Command transaction followed by an exact-length read transaction |
| Logical Device ID | `0x0102` | TEMT6000 identity; independent of the I2C address |
| Firmware / hardware | 1.0 / 1.0 | Current observable controller profile |
| Capability bitmap | `0x000001B9` | I2C configuration, analog input, sensor data, relay, watchdog, and persistent configuration |
| Raw digital sample | `0` to `4095` | 12-bit ADC code returned as an unsigned 16-bit little-endian value |
| ADC update interval | Approximately 20 ms | Background acquisition; an I2C read returns the latest published sample |
| Command processing delay | 2 to 5 ms | Use 5 ms conservatively before reading |
| Pending setter timeout | 250 ms | Parameter must arrive before expiry |

These values describe the currently documented digital behavior. Detailed DDP
commands and transaction sequences are provided in Chapter 3.

### **2.3 Onboard Interface Controller**

The onboard controller acquires the analog output of the TEMT6000 and provides
the processed sensor data through the module's I2C interface. The controller is
not exposed as a general-purpose microcontroller and is not intended for
user programming.

| Feature | Module implementation |
|---|---|
| Internal controller | 32-bit Arm Cortex-M0+ |
| Sensor acquisition | 12-bit ADC |
| User digital interface | I2C |
| I2C addressing | 7-bit addressing |
| Supported I2C clock | 100 kHz and 400 kHz |
| Direct sensor access | Analog `SIG` contact |
| Programming and debugging | Reserved for factory use |

### **2.4 TEMT6000 Maximum Ratings**

These component-level reference ratings describe a TEMT6000 profile. They are
not absolute maximum ratings for the complete module and do not establish
limits for the controller, indicators, pull-ups, connectors, or other board
components.

| Parameter | Symbol | Value | Unit |
|---|---:|---:|---|
| Collector-emitter voltage | `VCEO` | 6 | V |
| Emitter-collector voltage | `VECO` | 1.5 | V |
| Collector current | `IC` | 20 | mA |
| Power dissipation at 25 °C | `PV` | 100 | mW |
| Junction temperature | `Tj` | 100 | °C |
| Component operating temperature | `Tamb` | −40 to +100 | °C |

### **2.5 TEMT6000 Characteristics** {.section-page}

The following component-level reference characteristics apply at 25 °C unless
otherwise noted. They are not guaranteed complete-module performance values.

| Parameter | Test condition | Min. | Typ. | Max. | Unit |
|---|---|---:|---:|---:|---|
| Collector dark current | `VCE = 5 V`, `Ev = 0` | — | 3 | 50 | nA |
| Collector light current | `Ev = 20 lx`, CIE illuminant A, `VCE = 5 V` | 3.5 | 10 | 16 | µA |
| Collector light current | `Ev = 100 lx`, CIE illuminant A, `VCE = 5 V` | — | 50 | — | µA |
| Collector-emitter capacitance | `VCE = 0 V`, `f = 1 MHz`, dark | — | 16 | — | pF |
| Collector-emitter saturation voltage | `Ev = 20 lx`, `IPCE = 1.2 µA` | — | 0.1 | — | V |
| Angle of half sensitivity | — | — | ±60 | — | degrees |
| Peak sensitivity wavelength | — | — | 570 | — | nm |
| Spectral bandwidth at half sensitivity | — | 440 | — | 800 | nm |

### **2.6 Analog Signal Path**

The TEMT6000 analog signal is developed across a 10 kΩ resistor (`R1`) to
ground. The resulting `SIGNAL` net is connected to the controller ADC input and
the external `VCC`/`GND`/`SIG` contacts.

As a first-order estimate, `VSIGNAL ≈ IPCE × 10 kΩ` outside saturation. Applying the typical 100 lx photocurrent from the comparative TEMT6000 data gives an estimated signal of approximately 0.50 V. This calculation is an engineering estimate and must not be interpreted as a guaranteed or calibrated lux output.

The direct `SIG` range, analog transfer accuracy, source impedance, loading behavior, and complete-module response still require measurement and qualification.

### **2.7 Module-Level Characteristics**

The following characteristics are established for the current module
implementation and are described in the preceding sections.

| Characteristic | Current module specification |
|---|---|
| Nominal supply voltage | 3.3 V or 5 V |
| Digital interface | I2C, 7-bit slave |
| Factory I2C address | `0x20` |
| Configurable I2C address range | `0x08` to `0x77` |
| I2C clock frequency | 100 kHz to 400 kHz |
| Sensor acquisition | 12-bit ADC |
| Raw digital output | 0 to 4095 |
| ADC update interval | Approximately 20 ms |
| Command processing delay | 2 to 5 ms |
| Direct analog access | `SIG` contact connected to the TEMT6000 signal path |
| Sensor load resistor | 10 kΩ to GND |

Additional characteristics such as complete-module absolute maximum ratings,
supply-current limits, guaranteed analog-output accuracy, calibrated lux
accuracy, board-level operating-temperature range, and environmental
qualification are not specified unless explicitly stated elsewhere in this
Product Reference.

Component-level ratings shall not be interpreted as guaranteed ratings of the
complete module.

### **2.8 Electrical Precautions**

1. Use a current-limited 3.3 V or 5 V supply during engineering bring-up.
2. Verify connector orientation and establish a common ground before applying power.
3. Do not exceed the controller upper operating-voltage limit of 5.5 V.
4. When operating the module at 5 V, verify host compatibility with the actual voltage present on `SDA`, `SCL`, and `SIG`. Use appropriate level translation when required.
5. During normal operation, use the I2C connection points only for I2C communication. The same physical signals are shared with the controller's factory programming and debugging functions; SWD is not provided as a separate user interface.
6. Do not attempt firmware replacement or external debugging through the I2C connection points. Programming, debugging, and reset functions are reserved for manufacturer use and factory diagnostics.
7. Remove power before cutting, soldering, or reworking the I2C disable bridge or optional connector positions.
8. Verify the current released schematic, component specifications, and interface documentation before production integration.

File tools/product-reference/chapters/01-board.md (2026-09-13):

## **1 The Board**

The design supports two host paths. A Qwiic-capable controller can attach
through the I2C positions, while an ADC-capable host or test instrument can
sample the exposed `SIG` contact directly. Factory programming and debugging
reuse the I2C signals; they are not a separate user interface.

### **1.1 Accessories** {.section-page}

The module is supplied with a Qwiic-compatible cable for connection to the I2C interface.

| Accessory | Purpose | Selection notes |
|---|---|---|
| JST/Qwiic-compatible cable | Connects `GND`, `VCC`, `SDA`, and `SCL` | Verify 1.00 mm pitch, connector orientation, and contact order against the populated connector |

### **1.2 Recommended Test Equipment** 

The following equipment may be used for integration, testing, and validation. These items are not included with the module.

| Equipment | Purpose | Selection notes |
|---|---|---|
| I2C-capable host | Scans and communicates with the module | Use 7-bit addressing and an I2C clock from 100 kHz through 400 kHz |
| Analog test lead or carrier | Provides access to `VCC`, `GND`, and `SIG` | `SIG` must connect to a voltage-compatible ADC input |
| Logic analyzer | Checks I2C communication activity | Use input thresholds compatible with the powered board |
| Reference lux meter | Supports optical calibration and validation | Required for quantitative illuminance validation |

### **1.3 Board Identification**

| Item | Value |
|---|---|
| Product | UNIT ATOM TEMT6000 Ambient Light Sensor |
| Brand / company | UNIT Electronics |
| Board ecosystem | DevLab |
| Product family | Atom |
| Product type | I2C-compatible and direct-analog ambient-light module |
| Optical component | TEMT6000 |
| Interface controller | 32-bit Arm Cortex-M0+; 16 KB Flash and 2 KB SRAM |
| Manufacturer Part Number (MPN) | UE0098 |
| Current board artwork | |
| Product Reference | Version 1.1.0 |

Board, pinout, schematic, and documentation revisions are controlled
independently.

### **1.4 Board Components and Features**

| Component / Feature | Function | Implementation / Notes |
|---|---|---|
| TEMT6000 sensor | Converts visible light to photocurrent | Primary ambient-light sensing element |
| Interface controller | Samples and processes the sensor signal for I2C access | 32-bit Arm Cortex-M0+ with 16 KB Flash and 2 KB SRAM |
| I2C connections | Provide module power and I2C bus access | `J1` is populated by default; `J3` and `J4` support optional horizontal 4-pin, 1.00 mm-pitch JST/Qwiic-compatible connectors |
| Direct contacts | Provide direct access to `VCC`, `GND`, and analog `SIG` | Intended for analog signal access and external ADC measurement |
| I2C disable bridge | Allows the I2C interface to be disabled | Cut `JP1` to disable I2C operation |
| Power indicator | Indicates that the board is powered | Onboard `PWR` indicator |
| Built-in status indicator | Provides firmware-controlled status indication | Onboard `USR_LED` indicator |
| Reserved expansion pads | Provide connections reserved for future expansion | No user function is currently assigned |
| Factory service functions | Support controller programming, debugging, and reset | Reserved for manufacturer use; programming signals share the I2C interface |

### **1.5 Board Layout and Reference Designators** {.section-page}



**Figure 1.1 — Location of components and reference designators on the top and
bottom sides of the PCB.**

This drawing is a component-location reference. It helps locate parts named in
the schematic and in the table below; it does not define connector pin order
or indicate that every connector footprint is populated.

The top side contains the TEMT6000 sensor (`Q1`), interface controller (`IC1`),
direct `VCC`/`GND`/`SIG` contacts (`J2`), and the I2C connector installed by
default (`J1`). The bottom side provides two additional footprints, `J3` and
`J4`, for optional horizontal I2C connectors. `J1`, `J3`, and `J4` carry the
same `GND`, `VCC`, `SDA`, and `SCL` signals and provide access to the same I2C
bus.

The drawing also locates the I2C-disable bridge (`JP1`), the power and status
indicators, and factory test points. Refer to Chapter 4 for user connections
and to the released schematic for circuit-level information.

| Ref. | Description |
|---|---|
| `Q1` | TEMT6000 ambient-light sensor |
| `IC1` | Onboard interface controller |
| `J1` | Factory-populated 4-pin, 1.00 mm-pitch I2C connector |
| `J3`, `J4` | Two optional horizontal 4-pin, 1.00 mm-pitch I2C connector positions |
| `J2` | Direct `VCC`/`GND`/`SIG` contacts |
| `JP1` | Cuttable bridge for disabling I2C operation |
| `PWR` | Power indicator |
| `USR_LED` | Built-in status indicator |
| `TP1`–`TP7` | Factory test points |

### **1.5 Board Views** {.section-page}



The top view shows the direct sensor contacts, controller, sensor, mounting
hole, indicator circuitry, and the factory-populated I2C connector.

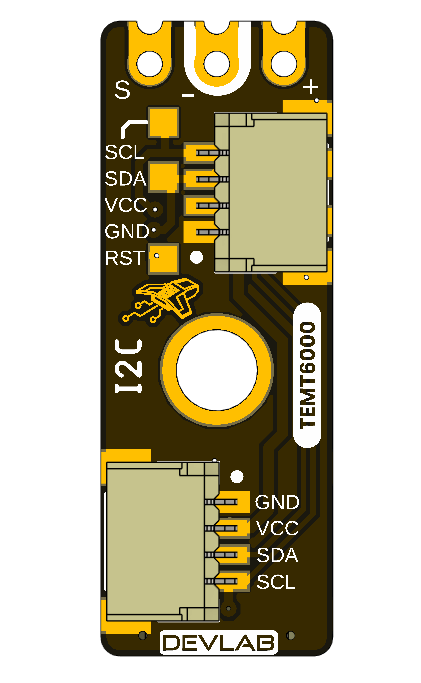
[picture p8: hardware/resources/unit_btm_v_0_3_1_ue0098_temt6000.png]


The bottom view shows the I2C connection points, reserved expansion pads,
factory service markings, and the optional horizontal connector positions.
The I2C signals are shared with the controller's factory programming and
debugging interface; there is no separate user-accessible SWD connector.

### **1.6 Handling** {.section-page}

Use normal ESD precautions. Keep the transparent sensor package clean and optically unobstructed. Remove power before changing connectors or modifying the I2C solder bridge.

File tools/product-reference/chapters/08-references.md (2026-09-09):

## **8 Reference Documentation**

| Reference | Location |
|---|---|
| Board topology | [Current resource](https://github.com/UNIT-Electronics-MX/unit_devlab_temt600_ambient_light_sensor/blob/main/hardware/resources/unit_topology_v_3_1_0_ue0098_temt6000_ambient_light_sens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) |
| Board dimensions | [Current resource](https://github.com/UNIT-Electronics-MX/unit_devlab_temt600_ambient_light_sensor/blob/main/hardware/resources/unit_dimensions_v_3_1_0_ue0098_temt6000_ambient_light_se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) |
| Product repository | [UNIT-Electronics-MX/unit_devlab_temt600_ambient_light_sensor](https://github.com/UNIT-Electronics-MX/unit_devlab_temt600_ambient_light_sensor) |
| Hardware reference | [hardware/README.md](https://github.com/UNIT-Electronics-MX/unit_devlab_temt600_ambient_light_sensor/blob/main/hardware/README.md) |
| English pinout | [Released pinout — English](https://github.com/UNIT-Electronics-MX/unit_devlab_temt600_ambient_light_sensor/blob/main/hardware/unit_pinout_v_3_1_0_ue0098_temt6000_ambient_light_sensor_en.pdf) |
| Spanish pinout | [Released pinout — Spanish](https://github.com/UNIT-Electronics-MX/unit_devlab_temt600_ambient_light_sensor/blob/main/hardware/unit_pinout_v_3_1_0_ue0098_temt6000_ambient_light_sensor_es.pdf) |
| Board top view | [V0.3.1 resource](https://github.com/UNIT-Electronics-MX/unit_devlab_temt600_ambient_light_sensor/blob/main/hardware/resources/unit_top_v_0_3_1_ue0098_temt6000.png) |
| Board bottom view | [V0.3.1 resource](https://github.com/UNIT-Electronics-MX/unit_devlab_temt600_ambient_light_sensor/blob/main/hardware/resources/unit_btm_v_0_3_1_ue0098_temt6000.png) |
| Current schematic | [V2.0.0](https://github.com/UNIT-Electronics-MX/unit_devlab_temt6000_ambient_light_sensor/blob/main/hardware/unit_sch_v_2_0_0_ue0098_temt6000.pdf) |
| Software examples | [C++ and MicroPython](https://github.com/UNIT-Electronics-MX/unit_devlab_temt600_ambient_light_sensor/tree/main/software/examples) |
| Arduino library | [UNIT-Electronics-MX/unit_devlab_temt6000_library](https://github.com/UNIT-Electronics-MX/unit_devlab_temt6000_library) |
| Local DDP device profile | [TEMT6000 DDP profile](https://github.com/UNIT-Electronics-MX/unit_devlab_temt600_ambient_light_sensor/blob/main/software/protocol/README.md) |
| Canonical DDP definitions and Arduino library | [UNIT-Electronics-Labs/unit_devlab_ddp_library](https://github.com/UNIT-Electronics-Labs/unit_devlab_ddp_library) |
| Comparative component page | [Vishay TEMT6000X01 — reference only](https://www.vishay.com/en/product/81579/) |
| TEMT6000 component datasheet | [Vishay Semiconductors, *TEMT6000X01 Ambient Light Sensor*, document 81579 — comparative reference only](https://www.vishay.com/docs/81579/temt6000.pdf) |

The released pinout, current board images, topology, dimensions, and schematic
define the current visible interfaces, board layout, and
mechanical envelope. The Vishay datasheet is
retained only as a comparative TEMT6000X01 profile; it does not establish the
exact orderable part fitted to this module or define complete-module ratings.
The DDP profile defines runtime identity and digital data transport; it does
not replace module-level electrical qualification.

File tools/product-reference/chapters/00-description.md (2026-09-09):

## **Description**

The UNIT ATOM TEMT6000 is an ambient-light sensor module developed by UNIT Electronics as part of the DevLab ecosystem. It combines a TEMT6000 visible-light phototransistor with an onboard interface controller, providing both I2C communication and direct access to the sensor’s analog signal.

The board provides direct VCC, GND, and SIG contacts, reserved expansion pads, power and status indicators, and a solder bridge for disabling the I2C interface. The onboard controller acquires the TEMT6000 signal through its analog-to-digital converter (ADC) and makes the resulting measurements available through the I2C interface.

### **Applications**

- I2C-connected ambient-light acquisition
- Direct analog light measurement during development and calibration
- Automatic display and indicator brightness control
- Day/night and relative-light detection
- Environmental data logging
- Educational I2C, ADC, and phototransistor experiments

### **DevLab Format Compatibility**

As part of the DevLab Atom family, the TEMT6000 module follows a compact and standardized form factor intended for rapid prototyping and integration with other DevLab modules. The board provides three 4-pin, 1.00 mm-pitch I2C connection positions carrying GND, VCC, SDA, and SCL. One connector is populated by default, while two additional horizontal positions are available for optional JST/Qwiic-compatible connectors. This arrangement provides multiple physical access points to the same I2C interface and supports different module integration and mounting configurations.

The module is designed for nominal 3.3 V or 5 V operation. Before connecting it to a host, verify the supply voltage, I2C pull-up voltage, connector orientation, and applicable electrical ratings. When operating the module at 5 V with a 3.3 V host, level translation may be required.

### **Hardware Features**

- TEMT6000 ambient-light phototransistor
- 32-bit Arm Cortex-M0+ controller with 16 KB Flash and 2 KB SRAM, using its internal HSI at up to 24 MHz
- Nominal 3.3 V and 5 V operation; controller upper operating limit of 5.5 V
- 7-bit I2C slave operation from 100 kHz to 400 kHz
- Three I2C connection positions carrying `GND`, `VCC`, `SDA`, and `SCL`: one populated by default and two optional horizontal positions
- Direct analog `SIG` access with adjacent `VCC` and `GND` contacts
- Two reserved expansion pads with no current application assignment
- Internal ADC acquisition of the TEMT6000 analog signal
- Shared I2C and factory programming signals
- Factory-only SWD/reset functions, power indicator, and built-in status indicator
- Cuttable solder bridge for disabling I2C operation
- Manufacturer Part Number (MPN): `UE0098`

The controller implements DevLab Device Protocol (DDP) v1.0. The TEMT6000 profile is identified by Device ID `0x0102`; command `TEMT6000_RAW` (`0x80`) returns a 12-bit ADC sample in an unsigned 16-bit little-endian response. The current controller firmware reports factory address `0x20`, firmware/hardware version 1.0, and capabilities `0x000001B9`.

The I2C data and clock signals are shared with the controller's factory programming interface; therefore, I2C communication and SWD programming cannot be used simultaneously. SWD and reset functions are reserved for manufacturer programming and advanced factory diagnostics, not for user firmware replacement.

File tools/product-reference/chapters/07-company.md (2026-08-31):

## **7 Company Information**

| Item | Information |
|---|---|
| Company / brand | UNIT Electronics |
| Board ecosystem | DevLab |
| Product family | Atom |
| Website | [UNIT Electronics](https://uelectronics.com/) |
| Address | Salvador 19, Cuauhtémoc, 06000 Mexico City, CDMX, Mexico |

The product repository and controlled technical references are listed in the
next chapter.

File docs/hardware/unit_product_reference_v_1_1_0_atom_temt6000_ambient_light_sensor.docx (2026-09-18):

# UNIT ATOM TEMT6000

I2C-Compatible Ambient Light Sensor — Hardware Revision V0.3.1

UNIT Electronics

2026-08-31

## Contents

- Description
  - Applications
  - DevLab Format Compatibility
  - Hardware Features
- 1 The Board
  - 1.1 Accessories {.section-page}
  - 1.2 Recommended Test Equipment
  - 1.3 Board Identification
  - 1.4 Board Components and Features
  - 1.5 Board Layout and Reference Designators {.section-page}
  - 1.5 Board Views {.section-page}
  - 1.6 Handling {.section-page}
- 2 Ratings
  - 2.1 Recommended Operating Conditions {.section-page}
  - 2.2 Digital Interface and Firmware Characteristics
  - 2.3 Onboard Interface Controller
  - 2.4 TEMT6000 Maximum Ratings
  - 2.5 TEMT6000 Characteristics {.section-page}
  - 2.6 Analog Signal Path
  - 2.7 Module-Level Characteristics
  - 2.8 Electrical Precautions
- 3 Functional Overview
  - 3.1 Functional Block Diagram {.section-page}
  - 3.2 Operating Modes
  - 3.3 Digital Light Measurement {.page-break}
  - 3.4 I2C Communication Model {.page-break}
  - 3.5 User-Accessible DDP Functions {.section-page}
  - 3.6 Built-In Indicator
  - 3.7 Physical Interface Notes {.section-page}
- 4 Connectors & Pinouts
  - 4.1 General Pinout {.section-page}
  - 4.2 Signal and I2C Connection Guide {.page-break}
  - 4.3 Direct Sensor Contacts
  - 4.4 I2C Connection Positions {.section-page}
  - 4.5 Auxiliary and Factory Service Functions
  - 4.6 Indicators and I2C Bridge
- 5 Board Operation
  - 5.1 Required Hardware and Software {.section-page}
  - 5.2 Library Installation
  - 5.3 I2C Connection and Example Settings {.page-break}
  - 5.4 Single-Sensor Arduino Example {.page-break}
  - 5.5 Upload and Serial Output {.section-page}
  - 5.6 Troubleshooting {.section-page}
- 6 Mechanical Information
  - 6.1 Board Dimensions {.section-page}
  - 6.2 Integration Clearances {.section-page}
  - 6.3 Mechanical Data Not Specified
- 7 Company Information
- 8 Reference Documentation
- 9 Appendix
  - 9.1 Current V2.0.0 Schematic {.section-page}
  - 9.2 Document Control {.section-page}
  - 9.3 Technical Data Not Specified in This Revision

## Description

The UNIT ATOM TEMT6000 is an ambient-light sensor module developed by UNIT Electronics as part of the DevLab ecosystem. It combines a TEMT6000 visible-light phototransistor with an onboard interface controller, providing both I2C communication and direct access to the sensor’s analog signal.

The board provides direct VCC, GND, and SIG contacts, reserved expansion pads, power and status indicators, and a solder bridge for disabling the I2C interface. The onboard controller acquires the TEMT6000 signal through its analog-to-digital converter (ADC) and makes the resulting measurements available through the I2C interface.

### Applications

- I2C-connected ambient-light acquisition
- Direct analog light measurement during development and calibration
- Automatic display and indicator brightness control
- Day/night and relative-light detection
- Environmental data logging
- Educational I2C, ADC, and phototransistor experiments

### DevLab Format Compatibility

As part of the DevLab Atom family, the TEMT6000 module follows a compact and standardized form factor intended for rapid prototyping and integration with other DevLab modules. The board provides three 4-pin, 1.00 mm-pitch I2C connection positions carrying GND, VCC, SDA, and SCL. One connector is populated by default, while two additional horizontal positions are available for optional JST/Qwiic-compatible connectors. This arrangement provides multiple physical access points to the same I2C interface and supports different module integration and mounting configurations.

The module is designed for nominal 3.3 V or 5 V operation. Before connecting it to a host, verify the supply voltage, I2C pull-up voltage, connector orientation, and applicable electrical ratings. When operating the module at 5 V with a 3.3 V host, level translation may be required.

### Hardware Features

- TEMT6000 ambient-light phototransistor
- 32-bit Arm Cortex-M0+ controller with 16 KB Flash and 2 KB SRAM, using its internal HSI at up to 24 MHz
- Nominal 3.3 V and 5 V operation; controller upper operating limit of 5.5 V
- 7-bit I2C slave operation from 100 kHz to 400 kHz
- Three I2C connection positions carrying GND, VCC, SDA, and SCL: one populated by default and two optional horizontal positions
- Direct analog SIG access with adjacent VCC and GND contacts
- Two reserved expansion pads with no current application assignment
- Internal ADC acquisition of the TEMT6000 analog signal
- Shared I2C and factory programming signals
- Factory-only SWD/reset functions, power indicator, and built-in status indicator
- Cuttable solder bridge for disabling I2C operation
- Manufacturer Part Number (MPN): UE0098

The controller implements DevLab Device Protocol (DDP) v1.0. The TEMT6000 profile is identified by Device ID 0x0102; command TEMT6000_RAW (0x80) returns a 12-bit ADC sample in an unsigned 16-bit little-endian response. The current controller firmware reports factory address 0x20, firmware/hardware version 1.0, and capabilities 0x000001B9.

The I2C data and clock signals are shared with the controller’s factory programming interface; therefore, I2C communication and SWD programming cannot be used simultaneously. SWD and reset functions are reserved for manufacturer programming and advanced factory diagnostics, not for user firmware replacement.

## 1 The Board

The design supports two host paths. A Qwiic-capable controller can attach through the I2C positions, while an ADC-capable host or test instrument can sample the exposed SIG contact directly. Factory programming and debugging reuse the I2C signals; they are not a separate user interface.

### 1.1 Accessories

The module is supplied with a Qwiic-compatible cable for connection to the I2C interface.

Accessory | Purpose | Selection notes
JST/Qwiic-compatible cable | Connects GND, VCC, SDA, and SCL | Verify 1.00 mm pitch, connector orientation, and contact order against the populated connector

### 1.2 Recommended Test Equipment

The following equipment may be used for integration, testing, and validation. These items are not included with the module.

Equipment | Purpose | Selection notes
I2C-capable host | Scans and communicates with the module | Use 7-bit addressing and an I2C clock from 100 kHz through 400 kHz
Analog test lead or carrier | Provides access to VCC, GND, and SIG | SIG must connect to a voltage-compatible ADC input
Logic analyzer | Checks I2C communication activity | Use input thresholds compatible with the powered board
Reference lux meter | Supports optical calibration and validation | Required for quantitative illuminance validation

### 1.3 Board Identification

Item | Value
Product | UNIT ATOM TEMT6000 Ambient Light Sensor
Brand / company | UNIT Electronics
Board ecosystem | DevLab
Product family | Atom
Product type | I2C-compatible and direct-analog ambient-light module
Optical component | TEMT6000
Interface controller | 32-bit Arm Cortex-M0+; 16 KB Flash and 2 KB SRAM
Manufacturer Part Number (MPN) | UE0098
Current board artwork
Product Reference | Version 1.1.0

Board, pinout, schematic, and documentation revisions are controlled independently.

### 1.4 Board Components and Features

Component / Feature | Function | Implementation / Notes
TEMT6000 sensor | Converts visible light to photocurrent | Primary ambient-light sensing element
Interface controller | Samples and processes the sensor signal for I2C access | 32-bit Arm Cortex-M0+ with 16 KB Flash and 2 KB SRAM
I2C connections | Provide module power and I2C bus access | J1 is populated by default; J3 and J4 support optional horizontal 4-pin, 1.00 mm-pitch JST/Qwiic-compatible connectors
Direct contacts | Provide direct access to VCC, GND, and analog SIG | Intended for analog signal access and external ADC measurement
I2C disable bridge | Allows the I2C interface to be disabled | Cut JP1 to disable I2C operation
Power indicator | Indicates that the board is powered | Onboard PWR indicator
Built-in status indicator | Provides firmware-controlled status indication | Onboard USR_LED indicator
Reserved expansion pads | Provide connections reserved for future expansion | No user function is currently assigned
Factory service functions | Support controller programming, debugging, and reset | Reserved for manufacturer use; programming signals share the I2C interface

### 1.5 Board Layout and Reference Designators

Figure 1.1 — Location of components and reference designators on the top and bottom sides of the PCB.

This drawing is a component-location reference. It helps locate parts named in the schematic and in the table below; it does not define connector pin order or indicate that every connector footprint is populated.

The top side contains the TEMT6000 sensor (Q1), interface controller (IC1), direct VCC/GND/SIG contacts (J2), and the I2C connector installed by default (J1). The bottom side provides two additional footprints, J3 and J4, for optional horizontal I2C connectors. J1, J3, and J4 carry the same GND, VCC, SDA, and SCL signals and provide access to the same I2C bus.

The drawing also locates the I2C-disable bridge (JP1), the power and status indicators, and factory test points. Refer to Chapter 4 for user connections and to the released schematic for circuit-level information.

Ref. | Description
Q1 | TEMT6000 ambient-light sensor
IC1 | Onboard interface controller
J1 | Factory-populated 4-pin, 1.00 mm-pitch I2C connector
J3, J4 | Two optional horizontal 4-pin, 1.00 mm-pitch I2C connector positions
J2 | Direct VCC/GND/SIG contacts
JP1 | Cuttable bridge for disabling I2C operation
PWR | Power indicator
USR_LED | Built-in status indicator
TP1–TP7 | Factory test points

### 1.5 Board Views


The top view shows the direct sensor contacts, controller, sensor, mounting hole, indicator circuitry, and the factory-populated I2C connector.


The bottom view shows the I2C connection points, reserved expansion pads, factory service markings, and the optional horizontal connector positions. The I2C signals are shared with the controller’s factory programming and debugging interface; there is no separate user-accessible SWD connector.

### 1.6 Handling

Use normal ESD precautions. Keep the transparent sensor package clean and optically unobstructed. Remove power before changing connectors or modifying the I2C solder bridge.

## 2 Ratings

This chapter summarizes the electrical operating conditions and interface characteristics relevant to integrating the UNIT ATOM TEMT6000. It covers the module supply, I2C operation, analog sensor path, controller capabilities, and ambient-light sensor characteristics. Use these ratings to select a compatible power source and host interface and to identify the electrical characteristics that require application-specific verification.

### 2.1 Recommended Operating Conditions

Symbol | Description | Min. | Typ. | Max. | Unit
VCC | Module supply voltage | — | 3.3 or 5 | — | V
VI2C | I2C logic-high and pull-up voltage | — | VCC | — | V
fSCL | I2C clock frequency | 100 | — | 400 | kHz
VSIG | Direct analog SIG voltage range | — | Not specified | — | V
ICC | Module supply current | — | Not specified | — | mA
TA | Module ambient operating temperature | Not specified | — | Not specified | °C

The VCC values are the supported nominal operating points; they are not complete-module absolute maximum ratings. The validated continuous supply range around each nominal point is not specified.

Use a current-limited source during initial bring-up. The I2C pull-ups follow the module supply, so the host must tolerate the actual bus voltage. When the module operates at 5 V with a 3.3 V host, bidirectional level translation may be required.

The direct SIG range requires analog-stage verification and measurement. Module current consumption must include the controller, indicators, pull-ups, and sensor load. The complete-module ambient-temperature range has not been qualified. I2C pull-up resistance, bus capacitance, and complete-module absolute maximum ratings are also not specified.

### 2.2 Digital Interface and Firmware Characteristics

Parameter | Value | Description
I2C addressing | 7-bit slave | Valid configurable addresses are 0x08..0x77
Factory I2C address | 0x20 (7-bit) | Pass 0x20 directly to the host I2C library; 0x40 is the 8-bit write address, not the device address
Device protocol | DDP v1.0 | Command transaction followed by an exact-length read transaction
Logical Device ID | 0x0102 | TEMT6000 identity; independent of the I2C address
Firmware / hardware | 1.0 / 1.0 | Current observable controller profile
Capability bitmap | 0x000001B9 | I2C configuration, analog input, sensor data, relay, watchdog, and persistent configuration
Raw digital sample | 0 to 4095 | 12-bit ADC code returned as an unsigned 16-bit little-endian value
ADC update interval | Approximately 20 ms | Background acquisition; an I2C read returns the latest published sample
Command processing delay | 2 to 5 ms | Use 5 ms conservatively before reading
Pending setter timeout | 250 ms | Parameter must arrive before expiry

These values describe the currently documented digital behavior. Detailed DDP commands and transaction sequences are provided in Chapter 3.

### 2.3 Onboard Interface Controller

The onboard controller acquires the analog output of the TEMT6000 and provides the processed sensor data through the module’s I2C interface. The controller is not exposed as a general-purpose microcontroller and is not intended for user programming.

Feature | Module implementation
Internal controller | 32-bit Arm Cortex-M0+
Sensor acquisition | 12-bit ADC
User digital interface | I2C
I2C addressing | 7-bit addressing
Supported I2C clock | 100 kHz and 400 kHz
Direct sensor access | Analog SIG contact
Programming and debugging | Reserved for factory use

### 2.4 TEMT6000 Maximum Ratings

These component-level reference ratings describe a TEMT6000 profile. They are not absolute maximum ratings for the complete module and do not establish limits for the controller, indicators, pull-ups, connectors, or other board components.

Parameter | Symbol | Value | Unit
Collector-emitter voltage | VCEO | 6 | V
Emitter-collector voltage | VECO | 1.5 | V
Collector current | IC | 20 | mA
Power dissipation at 25 °C | PV | 100 | mW
Junction temperature | Tj | 100 | °C
Component operating temperature | Tamb | −40 to +100 | °C

### 2.5 TEMT6000 Characteristics

The following component-level reference characteristics apply at 25 °C unless otherwise noted. They are not guaranteed complete-module performance values.

Parameter | Test condition | Min. | Typ. | Max. | Unit
Collector dark current | VCE = 5 V, Ev = 0 | — | 3 | 50 | nA
Collector light current | Ev = 20 lx, CIE illuminant A, VCE = 5 V | 3.5 | 10 | 16 | µA
Collector light current | Ev = 100 lx, CIE illuminant A, VCE = 5 V | — | 50 | — | µA
Collector-emitter capacitance | VCE = 0 V, f = 1 MHz, dark | — | 16 | — | pF
Collector-emitter saturation voltage | Ev = 20 lx, IPCE = 1.2 µA | — | 0.1 | — | V
Angle of half sensitivity | — | — | ±60 | — | degrees
Peak sensitivity wavelength | — | — | 570 | — | nm
Spectral bandwidth at half sensitivity | — | 440 | — | 800 | nm

### 2.6 Analog Signal Path

The TEMT6000 analog signal is developed across a 10 kΩ resistor (R1) to ground. The resulting SIGNAL net is connected to the controller ADC input and the external VCC/GND/SIG contacts.

As a first-order estimate, VSIGNAL ≈ IPCE × 10 kΩ outside saturation. Applying the typical 100 lx photocurrent from the comparative TEMT6000 data gives an estimated signal of approximately 0.50 V. This calculation is an engineering estimate and must not be interpreted as a guaranteed or calibrated lux output.

The direct SIG range, analog transfer accuracy, source impedance, loading behavior, and complete-module response still require measurement and qualification.

### 2.7 Module-Level Characteristics

The following characteristics are established for the current module implementation and are described in the preceding sections.

Characteristic | Current module specification
Nominal supply voltage | 3.3 V or 5 V
Digital interface | I2C, 7-bit slave
Factory I2C address | 0x20
Configurable I2C address range | 0x08 to 0x77
I2C clock frequency | 100 kHz to 400 kHz
Sensor acquisition | 12-bit ADC
Raw digital output | 0 to 4095
ADC update interval | Approximately 20 ms
Command processing delay | 2 to 5 ms
Direct analog access | SIG contact connected to the TEMT6000 signal path
Sensor load resistor | 10 kΩ to GND

Additional characteristics such as complete-module absolute maximum ratings, supply-current limits, guaranteed analog-output accuracy, calibrated lux accuracy, board-level operating-temperature range, and environmental qualification are not specified unless explicitly stated elsewhere in this Product Reference.

Component-level ratings shall not be interpreted as guaranteed ratings of the complete module.

### 2.8 Electrical Precautions

1. Use a current-limited 3.3 V or 5 V supply during engineering bring-up.
2. Verify connector orientation and establish a common ground before applying power.
3. Do not exceed the controller upper operating-voltage limit of 5.5 V.
4. When operating the module at 5 V, verify host compatibility with the actual voltage present on SDA, SCL, and SIG. Use appropriate level translation when required.
5. During normal operation, use the I2C connection points only for I2C communication. The same physical signals are shared with the controller’s factory programming and debugging functions; SWD is not provided as a separate user interface.
6. Do not attempt firmware replacement or external debugging through the I2C connection points. Programming, debugging, and reset functions are reserved for manufacturer use and factory diagnostics.
7. Remove power before cutting, soldering, or reworking the I2C disable bridge or optional connector positions.
8. Verify the current released schematic, component specifications, and interface documentation before production integration.

## 3 Functional Overview

The UNIT ATOM TEMT6000 combines an ambient-light phototransistor with an onboard controller. The module provides two ways to observe light level: digital readings over I2C and direct access to the analog sensor signal at SIG.

The TEMT6000 itself is an analog device. The onboard controller samples its output, applies the selected averaging, and provides the latest raw reading through DevLab Device Protocol (DDP) v1.0.

### 3.1 Functional Block Diagram


Figure 3.1 — Functional signal and control paths. Ambient light changes the TEMT6000 output. The signal is available at SIG and is also acquired by the controller ADC for access over I2C.

### 3.2 Operating Modes

Mode | Connection | User-visible result
Digital I2C | VCC, GND, SDA, and SCL | Averaged 12-bit raw light reading through DDP
Direct analog | VCC, GND, and SIG | Light-dependent voltage for a host ADC or measurement instrument

Both modes observe the same sensor path. An I2C read returns the latest available sample; it does not trigger a new light measurement. The direct analog output may be used independently for development, comparison, or application-specific calibration.

### 3.3 Digital Light Measurement

The onboard ADC produces an unsigned 12-bit value. A higher value represents a higher sensor output under the actual supply, optical, and mechanical conditions.

Measurement property | Value
ADC resolution | 12 bits
Raw output range | 0..4095
Response format | Two bytes, [LSB, MSB]
Update interval | Approximately 20 ms
Selectable averaging | 1, 4, 8, 16, or 24 samples

The averaging setting controls the balance between response speed and stability:

Samples | Approximate time for a completely new average | Typical use
1 | 20 ms | Fast changes
4 | 80 ms | Low-latency smoothing
8 | 160 ms | General monitoring
16 | 320 ms | Stable ambient-light monitoring
24 | 480 ms | Maximum available smoothing

The result is a relative ADC reading, not a calibrated lux measurement. Quantitative lux measurements require calibration in the final enclosure and optical arrangement.

### 3.4 I2C Communication Model

The I2C host always initiates communication. The 7-bit I2C address selects the module, while the one-byte DDP selector identifies the requested function. These are independent values.


Figure 3.2 — DDP command and response over I2C. The host writes one DDP selector, issues STOP, waits 2–5 ms, and then reads the documented number of response bytes. The host acknowledges intermediate bytes and sends NACK after the final byte.

Communication property | Value
Factory 7-bit address | 0x20
Configurable address range | 0x08..0x77
I2C clock | 100 kHz to 400 kHz
Delay before response read | 2–5 ms; use 5 ms conservatively
Byte order for multi-byte values | Little endian
Supported response lengths | 1, 2, or 4 bytes, depending on the selected function

Pass 0x20 directly to an I2C library. Values 0x40 and 0x41 are the shifted write/read address bytes visible on the bus, not the 7-bit address used by typical host APIs.

### 3.5 User-Accessible DDP Functions

User function | DDP selector | Result
Identify the module | 0x00 | Device ID 0x0102
Read protocol version | 0x04 | DDP version 1.0
Read active I2C address | 0x20 | Current 7-bit address
Change I2C address | 0x21 | Stores and applies a new address in the valid range
Restore factory configuration | 0x23 | Restores default configuration; reset required
Read ambient-light data | 0x60 or 0x80 | Latest two-byte 12-bit raw sample
Set ADC averaging | 0x62 | Selects 1, 4, 8, 16, or 24 samples
Read ADC averaging | 0x63 | Returns the active averaging setting
Turn BUILTIN off/on | 0xA0 / 0xA1 | Drives the built-in indicator LOW/HIGH
Pulse BUILTIN | 0xA2 | Starts a non-blocking timed pulse
Set/read pulse time | 0xA3 / 0xA4 | Uses 1–40 units of 25 ms

The I2C address, averaging selection, and pulse duration are retained after a power cycle. Changing a stored value should be an occasional configuration operation rather than part of the normal measurement loop.

Detailed transaction handling is already implemented by the maintained C++ and MicroPython examples listed in Chapter 8.

### 3.6 Built-In Indicator

The built-in status indicator is controlled through the DDP actuator functions. The shared DDP command names contain RELAY, but this product uses them for the built-in indicator and does not provide an electromechanical relay output.

The pulse duration is configurable from 25 ms to 1000 ms in 25 ms steps. A timed pulse runs without interrupting light measurements or I2C communication.

### 3.7 Physical Interface Notes

The SIG contact provides direct access to the analog sensor path. Its complete board-level transfer function, source impedance, and guaranteed output range are not specified for the current revision. Use a high-impedance input and verify the actual range before connecting it to a lower-voltage ADC.

The PCB provides three I2C connection positions carrying GND, VCC, SDA, and SCL: one connector is populated by default and two horizontal positions are provided for optional 4-pin, 1.00 mm-pitch JST/Qwiic-compatible connectors. All three positions access the same I2C bus.

The I2C connection points share signals with the controller’s factory programming and debugging interface; there is no separate user-accessible SWD connector. Programming, debug, and reset functions are reserved for manufacturer programming and factory diagnostics, not user firmware replacement.

Two expansion pads are reserved and have no current user function. The I2C disable bridge is intended for applications that require the analog path without active I2C operation; remove power before cutting or restoring it.

## 4 Connectors & Pinouts

The user-accessible interfaces are described below by module function. The released documentation does not provide controlled contact numbers or a mating-connector part number, so the signal order must be checked against the connector orientation before producing a harness.

### 4.1 General Pinout

Connection group | Signals | Function
Direct sensor contacts | VCC, GND, SIG | Module power and direct access to the TEMT6000 analog signal
I2C connection positions | GND, VCC, SDA, SCL | Power and digital communication over the common I2C bus
Reserved expansion pads | Reserved | No current application assignment; electrical limits are not specified

The PCB has three physical I2C connection positions. One connector is populated by default, and two additional horizontal positions accept optional 4-pin, 1.00 mm-pitch JST/Qwiic-compatible connectors. All three positions are connected to the same I2C bus.

### 4.2 Signal and I2C Connection Guide


Figure 4.1 — Direct analog and I2C connection groups. The direct contacts provide SIG, GND, and VCC; the populated I2C connector provides SCL, SDA, VCC, and GND. Always follow the connector orientation shown on the board.

### 4.3 Direct Sensor Contacts

Label | Type | Description
VCC | Power | Module supply; nominal 3.3 V or 5 V operation
GND | Power | Common power and signal reference
SIG / SIGNAL | Analog | Direct light-dependent sensor signal; current transfer function unspecified

These three contacts are shown at the end opposite the populated I2C connector. SIG provides direct access to the TEMT6000 analog signal; it is not a separate specialized communication port.

### 4.4 I2C Connection Positions

Signal | Type | Description
GND | Power | Common return
VCC | Power | I2C peripheral supply; nominal 3.3 V or 5 V
SDA | Bidirectional I2C data | Host must tolerate the actual bus pull-up voltage
SCL | I2C clock | Supported at 100 kHz to 400 kHz

The two optional horizontal I2C connector positions use the same signal set and 1.00 mm pitch as the populated connector. Because all three positions are physical access points to the same bus, an optional connector may be used for an alternate cable orientation or bus continuation. Account for the loading and pull-ups of every attached device.

The I2C connection points share signals with the controller’s factory programming and debugging interface. These functions are mutually exclusive, and there is no separate user-accessible SWD connector.

### 4.5 Auxiliary and Factory Service Functions

Function | Documented role | Qualification status
Reserved expansion pad 1 | Reserved connection | No current application assignment; electrical limits unspecified
Reserved expansion pad 2 | Reserved connection | No current application assignment; electrical limits unspecified
Controller reset | Factory service function | Manufacturer programming and factory diagnostics only

Programming, debugging, and reset are intended primarily for development, manufacturing, and service purposes. Currently, user firmware programming is not supported or documented. During programming or diagnostics, I2C must be inactive and other bus devices must be isolated from the shared signals.

### 4.6 Indicators and I2C Bridge

The module provides a power indicator, a firmware-controlled built-in status indicator, and a normally closed solder bridge that connects the sensor’s raw output signal to the controller ADC input. Opening the bridge isolates the raw sensor signal from the ADC, and the connection can be restored by re-soldering the bridge. The controller ADC input used for sensor acquisition is internal to the module and is not an additional external contact.

## 5 Board Operation

This chapter shows how to verify one UNIT ATOM TEMT6000 and read its raw ambient-light value with Arduino. The example supports the Pulsar ESP32-C6 and Pulsar RP2350 host boards.

### 5.1 Required Hardware and Software

- UNIT ATOM TEMT6000 module
- Pulsar ESP32-C6 or Pulsar RP2350 development board
- I2C connection for VCC, GND, SDA, and SCL
- USB cable for programming and Serial Monitor access
- Arduino IDE with the selected board package installed
- DevLab_TEMT6000 Arduino library

### 5.2 Library Installation

1. Open Tools > Manage Libraries in Arduino IDE.
2. Search for DevLab_TEMT6000.
3. Select the current release and click Install.
4. Allow Arduino IDE to install the DevLabDDP dependency when prompted.

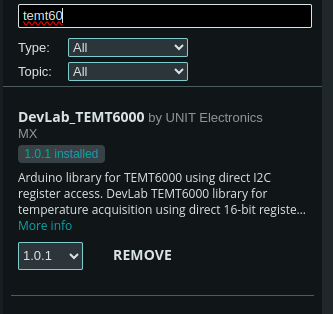
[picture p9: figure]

Figure 5.1 — DevLab_TEMT6000 in Arduino Library Manager. The installed package provides the TEMT6000 examples and installs the DDP communication dependency used by the sketch below.

### 5.3 I2C Connection and Example Settings

Connect the module with power removed.

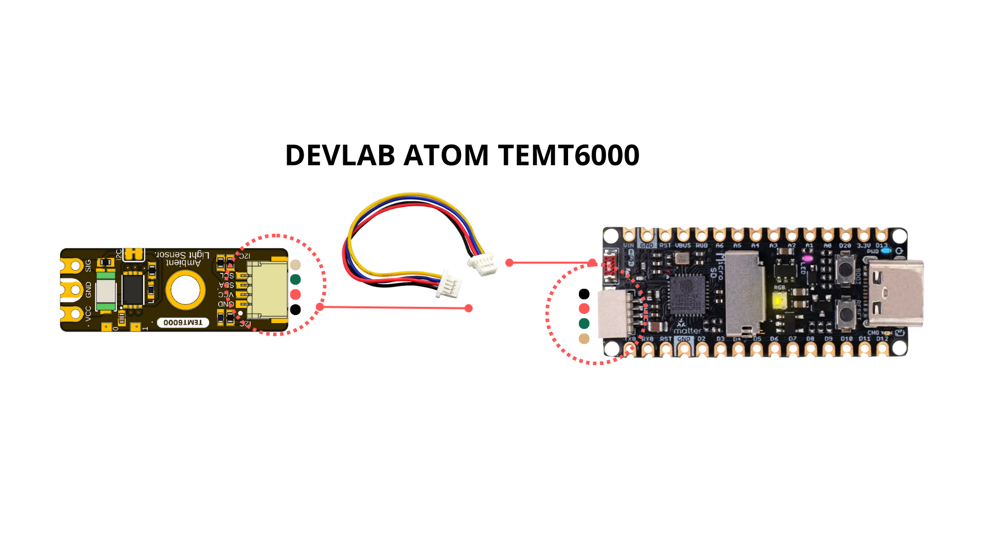
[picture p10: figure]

Figure 5.2 — I2C connection to a Pulsar ESP32-C6 host. Align the connector with the orientation shown and verify VCC, GND, SDA, and SCL before applying power.

Module | Pulsar ESP32-C6 | Pulsar RP2350 | Function
VCC | 3.3 V or 5 V | 3.3 V or 5 V | Module supply
GND | GND | GND | Common reference
SDA | GPIO6 | GPIO24 | I2C data
SCL | GPIO7 | GPIO25 | I2C clock

The pin numbers above match singleSensor.ino. Change I2C_SDA and I2C_SCL when the selected host board uses different I2C pins.

Important: The I2C pull-up voltage follows the module supply (VCC). When operating the module at 5 V, verify that the host I2C pins are 5 V tolerant. If the host operates at 3.3 V and is not 5 V tolerant, use appropriate bidirectional level translation between the module and the host.

The example uses the following settings:

Constant | Default | Purpose
I2C_SDA | GPIO6 on Pulsar ESP32-C6; GPIO24 on Pulsar RP2350 | Host SDA pin
I2C_SCL | GPIO7 on Pulsar ESP32-C6; GPIO25 on Pulsar RP2350 | Host SCL pin
I2C_FREQ | 400000 Hz | I2C clock
SENSOR_ADDRESS | 0x20 | Factory 7-bit module address
READ_INTERVAL_MS | 1000 ms | Time between printed readings

If the module address was changed previously, update SENSOR_ADDRESS before uploading the sketch.

### 5.4 Single-Sensor Arduino Example

Open or create singleSensor.ino, then use the following sketch:

/**
* @file singleSensor.ino
* @brief Verifies a single TEMT6000 DDP device on the I2C bus and prints
* its raw light readings over Serial at a fixed interval.
* @author Cesar Bautista
*/

#include <Arduino.h>
#include <Wire.h>
#include <DevLabDDP.h>
#include <DevLabI2CBusRecovery.h>

#if defined(ARDUINO_ARCH_RP2040)
#define I2C_BUS Wire
constexpr uint8_t I2C_SDA = 24U, I2C_SCL = 25U;
#elif defined(ARDUINO_ARCH_ESP32)
#define I2C_BUS Wire
constexpr uint8_t I2C_SDA = 6U, I2C_SCL = 7U;
#else
#error "Use Pulsar ESP32-C6 or Pulsar RP2350"
#endif

constexpr uint32_t I2C_FREQ = 400000;
constexpr uint8_t SENSOR_ADDRESS = 0x20;
constexpr uint32_t READ_INTERVAL_MS = 1000U;

DevLabDDP::Master master(I2C_BUS, DevLabDDP::DEVICE_TEMT6000);
bool deviceVerified = false;

void setup() {
Serial.begin(115200);
delay(500);

if (!devlabBeginI2cBusRecovered(
I2C_BUS, I2C_SDA, I2C_SCL, I2C_FREQ, 100)) {
Serial.println("ERROR: I2C bus is blocked");
return;
}

DevLabDDP::DeviceInfo info;
deviceVerified = master.matchesExpectedDevice(SENSOR_ADDRESS, &info);

if (!deviceVerified) {
Serial.println("ERROR: address is not a DDP TEMT6000 (ID 0x0102)");
return;
}

DevLabDDP::printDeviceInfo(
Serial,
SENSOR_ADDRESS,
info,
DevLabDDP::DEVICE_TEMT6000);

Serial.println("adc0_raw");
}

void loop() {
uint16_t raw;

if (deviceVerified && master.readAdc(SENSOR_ADDRESS, 0, raw)) {
Serial.println(raw);
} else {
Serial.println("ERR");
}

delay(READ_INTERVAL_MS);
}

### 5.5 Upload and Serial Output

1. Select the connected Pulsar ESP32-C6 or Pulsar RP2350 board in Arduino IDE.
2. Select its serial port.
3. Compile and upload singleSensor.ino.
4. Open Serial Monitor at 115200 baud.
5. Illuminate and cover the TEMT6000 to confirm that the printed value changes.

At startup, the sketch recovers and initializes the I2C bus, verifies that address 0x20 contains a DDP TEMT6000 with Device ID 0x0102, and prints the reported device information. It then prints the heading adc0_raw and one reading per second.

<DDP device information>
adc0_raw
<value from 0 to 4095>
<value from 0 to 4095>

The readings are raw ADC values. They indicate relative light level and must not be interpreted directly as lux.

### 5.6 Troubleshooting

Serial output or symptom | Check
ERROR: I2C bus is blocked | Wiring, connector orientation, shared ground, pull-up voltage, and unintended SDA/SCL drive
ERROR: address is not a DDP TEMT6000 (ID 0x0102) | Address setting, I2C pins, module power, and possible address collision
ERR after successful identification | Cable continuity, bus clock, supply stability, and I2C connections
Constant 0 or 4095 | Sensor obstruction, excessive illumination, supply, and module orientation
Values change but lux is inaccurate | Calibrate the complete optical installation against a reference light meter

The complete Arduino examples and the reusable DDP library are listed in Chapter 8.

## 6 Mechanical Information

The current mechanical drawing defines the board outline and the dimensions shown below. Dimensions are in millimetres.

### 6.1 Board Dimensions

Figure 6.1 — Board dimensions.

The drawing specifies a 27 mm × 10 mm board outline and a 3 mm mounting hole. It also shows the hole centerline 5 mm from the side edge and 10.8 mm from the connector-end edge. Use the drawing itself as the dimensional reference; do not derive additional dimensions by scaling the image.

### 6.2 Integration Clearances

Leave optical clearance around the transparent TEMT6000 sensor package and its field of view. Provide connector insertion and cable bend clearance at the populated I2C connector and at any optional connector position that will be assembled. Keep conductive fasteners away from contacts and factory service points, and avoid enclosure features that shadow the sensor or indicators.

### 6.3 Mechanical Data Not Specified

- Board thickness, dimensional tolerances, and finished mass
- Unannotated feature coordinates and edge clearances
- Optional connector population variants and mating-part numbers
- Connector insertion envelope, retention force, and cable bend radius
- Maximum top- and bottom-side component heights
- Optical axis, keep-out cone, and enclosure-window specification
- Reserved expansion-pad and factory service-point coordinates

## 7 Company Information

Item | Information
Company / brand | UNIT Electronics
Board ecosystem | DevLab
Product family | Atom
Website | UNIT Electronics (https://uelectronics.com/)
Address | Salvador 19, Cuauhtémoc, 06000 Mexico City, CDMX, Mexico

The product repository and controlled technical references are listed in the next chapter.

## 8 Reference Documentation

Reference | Location
Board topology | Current resource (https://github.com/UNIT-Electronics-MX/unit_devlab_temt600_ambient_light_sensor/blob/main/hardware/resources/unit_topology_v_3_1_0_ue0098_temt6000_ambient_lig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)
Board dimensions | Current resource (https://github.com/UNIT-Electronics-MX/unit_devlab_temt600_ambient_light_sensor/blob/main/hardware/resources/unit_dimensions_v_3_1_0_ue0098_temt6000_ambient_l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)
Product repository | UNIT-Electronics-MX/unit_devlab_temt600_ambient_light_sensor (https://github.com/UNIT-Electronics-MX/unit_devlab_temt600_ambient_light_sensor)
Hardware reference | hardware/README.md (https://github.com/UNIT-Electronics-MX/unit_devlab_temt600_ambient_light_sensor/blob/main/hardware/README.md)
English pinout | Released pinout — English (https://github.com/UNIT-Electronics-MX/unit_devlab_temt600_ambient_light_sensor/blob/main/hardware/unit_pinout_v_3_1_0_ue0098_temt6000_ambient_light_sensor_en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)
Spanish pinout | Released pinout — Spanish (https://github.com/UNIT-Electronics-MX/unit_devlab_temt600_ambient_light_sensor/blob/main/hardware/unit_pinout_v_3_1_0_ue0098_temt6000_ambient_light_sensor_es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)
Board top view | V0.3.1 resource (https://github.com/UNIT-Electronics-MX/unit_devlab_temt600_ambient_light_sensor/blob/main/hardware/resources/unit_top_v_0_3_1_ue0098_temt6000.png)
Board bottom view | V0.3.1 resource (https://github.com/UNIT-Electronics-MX/unit_devlab_temt600_ambient_light_sensor/blob/main/hardware/resources/unit_btm_v_0_3_1_ue0098_temt6000.png)
Current schematic | V2.0.0 (https://github.com/UNIT-Electronics-MX/unit_devlab_temt6000_ambient_light_sensor/blob/main/hardware/unit_sch_v_2_0_0_ue0098_temt6000.pdf)
Software examples | C++ and MicroPython (https://github.com/UNIT-Electronics-MX/unit_devlab_temt600_ambient_light_sensor/tree/main/software/examples)
Arduino library | UNIT-Electronics-MX/unit_devlab_temt6000_library (https://github.com/UNIT-Electronics-MX/unit_devlab_temt6000_library)
Local DDP device profile | TEMT6000 DDP profile (https://github.com/UNIT-Electronics-MX/unit_devlab_temt600_ambient_light_sensor/blob/main/software/protocol/README.md)
Canonical DDP definitions and Arduino library | UNIT-Electronics-Labs/unit_devlab_ddp_library (https://github.com/UNIT-Electronics-Labs/unit_devlab_ddp_library)
Comparative component page | Vishay TEMT6000X01 — reference only (https://www.vishay.com/en/product/81579/)
TEMT6000 component datasheet | Vishay Semiconductors, TEMT6000X01 Ambient Light Sensor, document 81579 — comparative reference only (https://www.vishay.com/docs/81579/temt6000.pdf)

The released pinout, current board images, topology, dimensions, and schematic define the current visible interfaces, board layout, and mechanical envelope. The Vishay datasheet is retained only as a comparative TEMT6000X01 profile; it does not establish the exact orderable part fitted to this module or define complete-module ratings. The DDP profile defines runtime identity and digital data transport; it does not replace module-level electrical qualification.

## 9 Appendix

### 9.1 Current V2.0.0 Schematic

The current schematic is documented in hardware/unit_sch_v_2_0_0_ue0098_temt6000.pdf. It documents the controller-based V0.3.1 board, including the reference controller, TEMT6000 analog stage, I2C interfaces, status indicators, test points, and optional connectors.


Figure 9.1 — Current V2.0.0 electrical schematic.

The sensor signal uses a 10 kΩ resistor (R1) to ground and is routed to the controller ADC input and the external VCC/GND/SIG header. As a first-order estimate outside saturation, VSIGNAL ≈ IPCE × 10 kΩ; this is not a calibrated or guaranteed conversion to lux.

The I2C SDA and SCL signals are available at three physical connection positions: one connector populated by default and two optional horizontal positions. These signals are shared with the controller’s factory programming and debugging interface; there is no separate user-accessible SWD connector.

### 9.2 Document Control

Field | Value
Product | UNIT ATOM TEMT6000 Ambient Light Sensor
Product hierarchy | UNIT Electronics → DevLab board ecosystem → Atom family
Manufacturer Part Number (MPN) | UE0098
Current board artwork | V0.3.1
Current pinout, topology, and dimensions | V3.1.0
Available schematic | Current V2.0.0
Product Reference | Version 1.1.0
Publication date | 2026-08-31
Interfaces | Three I2C connection positions on one bus; VCC/GND/SIG header; reserved expansion pads; shared factory programming/debug signals
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

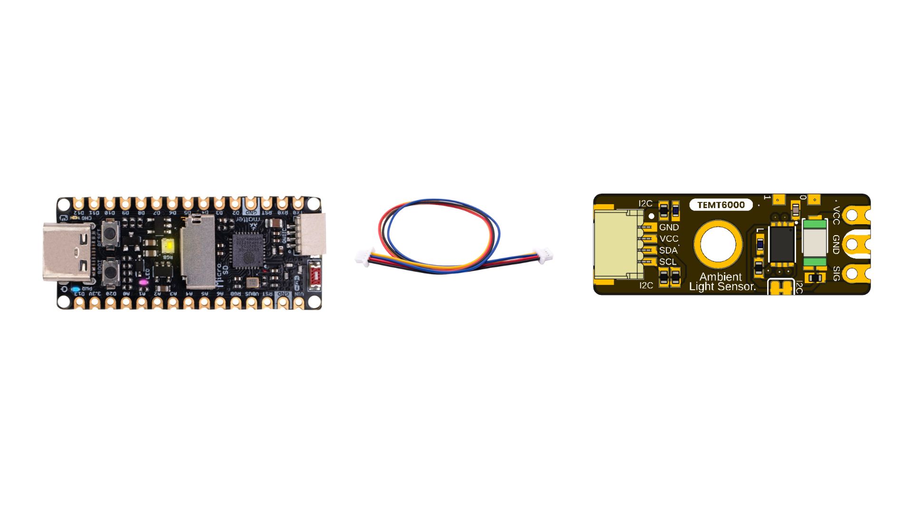
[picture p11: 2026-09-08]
docs/hardware/resources/wiki/Conn.jpg

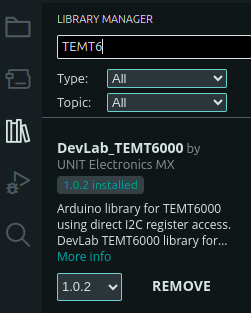
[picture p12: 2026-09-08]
docs/hardware/resources/wiki/library.png

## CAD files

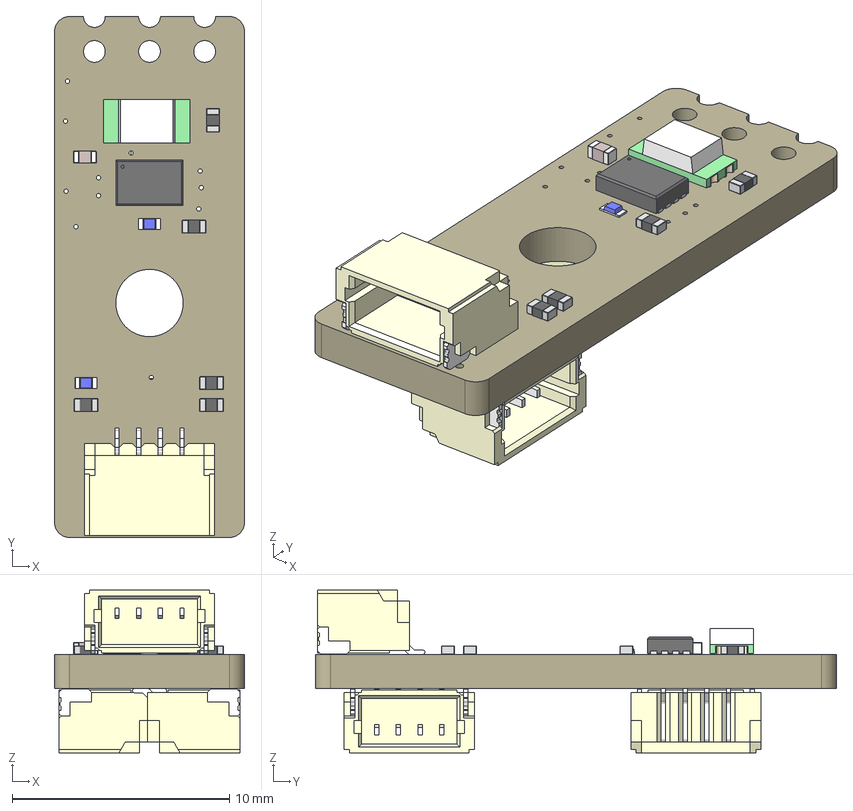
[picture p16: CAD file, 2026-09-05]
mechanics/unit_3d_ue0098_v_2_0_0_temt6000.step
8.75 x 24.0 x 7.49 mm
Placa
SM04B-SRSS-TB(LF)(SN)--3DModel-STEP-56544 v1 x 3
0402_R x 3
TEMT6000 v1
M3
R0402 x 2
BRIDGE
TP10SQ x 7

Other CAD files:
mechanics/unit_3d_ue0098_v_2_0_0_temt6000.f3d

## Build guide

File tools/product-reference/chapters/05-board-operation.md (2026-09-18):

## **5 Board Operation**

This chapter shows how to verify one UNIT ATOM TEMT6000 and read its raw
ambient-light value with Arduino. The example supports the Pulsar ESP32-C6 and
Pulsar RP2350 host boards.

### **5.1 Required Hardware and Software** {.section-page}

- UNIT ATOM TEMT6000 module
- Pulsar ESP32-C6 or Pulsar RP2350 development board
- I2C connection for `VCC`, `GND`, `SDA`, and `SCL`
- USB cable for programming and Serial Monitor access
- Arduino IDE with the selected board package installed
- `DevLab_TEMT6000` Arduino library

### **5.2 Library Installation**

1. Open **Tools > Manage Libraries** in Arduino IDE.
2. Search for `DevLab_TEMT6000`.
3. Select the current release and click **Install**.
4. Allow Arduino IDE to install the `DevLabDDP` dependency when prompted.



**Figure 5.1 — DevLab_TEMT6000 in Arduino Library Manager.** The installed
package provides the TEMT6000 examples and installs the DDP communication
dependency used by the sketch below.

### **5.3 I2C Connection and Example Settings** {.page-break}

Connect the module with power removed.



**Figure 5.2 — I2C connection to a Pulsar ESP32-C6 host.** Align the
connector with the orientation shown and verify `VCC`, `GND`, `SDA`, and `SCL`
before applying power.

| Module | Pulsar ESP32-C6 | Pulsar RP2350 | Function |
|---|---:|---:|---|
| `VCC` | 3.3 V or 5 V | 3.3 V or 5 V | Module supply |
| `GND` | `GND` | `GND` | Common reference |
| `SDA` | GPIO6 | GPIO24 | I2C data |
| `SCL` | GPIO7 | GPIO25 | I2C clock |

The pin numbers above match `singleSensor.ino`. Change `I2C_SDA` and `I2C_SCL` when the selected host board uses different I2C pins.

Important: The I2C pull-up voltage follows the module supply (VCC). When operating the module at 5 V, verify that the host I2C pins are 5 V tolerant. If the host operates at 3.3 V and is not 5 V tolerant, use appropriate bidirectional level translation between the module and the host.

The example uses the following settings:

| Constant | Default | Purpose |
|---|---:|---|
| `I2C_SDA` | GPIO6 on Pulsar ESP32-C6; GPIO24 on Pulsar RP2350 | Host SDA pin |
| `I2C_SCL` | GPIO7 on Pulsar ESP32-C6; GPIO25 on Pulsar RP2350 | Host SCL pin |
| `I2C_FREQ` | 400000 Hz | I2C clock |
| `SENSOR_ADDRESS` | `0x20` | Factory 7-bit module address |
| `READ_INTERVAL_MS` | 1000 ms | Time between printed readings |

If the module address was changed previously, update `SENSOR_ADDRESS` before
uploading the sketch.

### **5.4 Single-Sensor Arduino Example** {.page-break}

Open or create `singleSensor.ino`, then use the following sketch:

```{.cpp .compact-code}
/**
 * @file singleSensor.ino
 * @brief Verifies a single TEMT6000 DDP device on the I2C bus and prints
 *        its raw light readings over Serial at a fixed interval.
 * @author Cesar Bautista
 */

#include <Arduino.h>
#include <Wire.h>
#include <DevLabDDP.h>
#include <DevLabI2CBusRecovery.h>

#if defined(ARDUINO_ARCH_RP2040)
#define I2C_BUS Wire
constexpr uint8_t I2C_SDA = 24U, I2C_SCL = 25U;
#elif defined(ARDUINO_ARCH_ESP32)
#define I2C_BUS Wire
constexpr uint8_t I2C_SDA = 6U, I2C_SCL = 7U;
#else
#error "Use Pulsar ESP32-C6 or Pulsar RP2350"
#endif

constexpr uint32_t I2C_FREQ = 400000;
constexpr uint8_t SENSOR_ADDRESS = 0x20;
constexpr uint32_t READ_INTERVAL_MS = 1000U;

DevLabDDP::Master master(I2C_BUS, DevLabDDP::DEVICE_TEMT6000);
bool deviceVerified = false;

void setup() {
  Serial.begin(115200);
  delay(500);

  if (!devlabBeginI2cBusRecovered(
          I2C_BUS, I2C_SDA, I2C_SCL, I2C_FREQ, 100)) {
    Serial.println("ERROR: I2C bus is blocked");
    return;
  }

  DevLabDDP::DeviceInfo info;
  deviceVerified = master.matchesExpectedDevice(SENSOR_ADDRESS, &info);

  if (!deviceVerified) {
    Serial.println("ERROR: address is not a DDP TEMT6000 (ID 0x0102)");
    return;
  }

  DevLabDDP::printDeviceInfo(
      Serial,
      SENSOR_ADDRESS,
      info,
      DevLabDDP::DEVICE_TEMT6000);

  Serial.println("adc0_raw");
}

void loop() {
  uint16_t raw;

  if (deviceVerified && master.readAdc(SENSOR_ADDRESS, 0, raw)) {
    Serial.println(raw);
  } else {
    Serial.println("ERR");
  }

  delay(READ_INTERVAL_MS);
}
```

### **5.5 Upload and Serial Output** {.section-page}

1. Select the connected Pulsar ESP32-C6 or Pulsar RP2350 board in Arduino IDE.
2. Select its serial port.
3. Compile and upload `singleSensor.ino`.
4. Open Serial Monitor at **115200 baud**.
5. Illuminate and cover the TEMT6000 to confirm that the printed value changes.

At startup, the sketch recovers and initializes the I2C bus, verifies that
address `0x20` contains a DDP TEMT6000 with Device ID `0x0102`, and prints
the reported device information. It then prints the heading `adc0_raw` and one
reading per second.

```text
<DDP device information>
adc0_raw
<value from 0 to 4095>
<value from 0 to 4095>
```

The readings are raw ADC values. They indicate relative light level and must
not be interpreted directly as lux.

### **5.6 Troubleshooting** {.section-page}

| Serial output or symptom | Check |
|---|---|
| `ERROR: I2C bus is blocked` | Wiring, connector orientation, shared ground, pull-up voltage, and unintended SDA/SCL drive |
| `ERROR: address is not a DDP TEMT6000 (ID 0x0102)` | Address setting, I2C pins, module power, and possible address collision |
| `ERR` after successful identification | Cable continuity, bus clock, supply stability, and I2C connections |
| Constant `0` or `4095` | Sensor obstruction, excessive illumination, supply, and module orientation |
| Values change but lux is inaccurate | Calibrate the complete optical installation against a reference light meter |

The complete Arduino examples and the reusable DDP library are listed in
Chapter 8.

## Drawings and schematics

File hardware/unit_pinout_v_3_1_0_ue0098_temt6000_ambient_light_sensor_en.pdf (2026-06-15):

# PINOUT

# DevLab: I2C TEMT6000

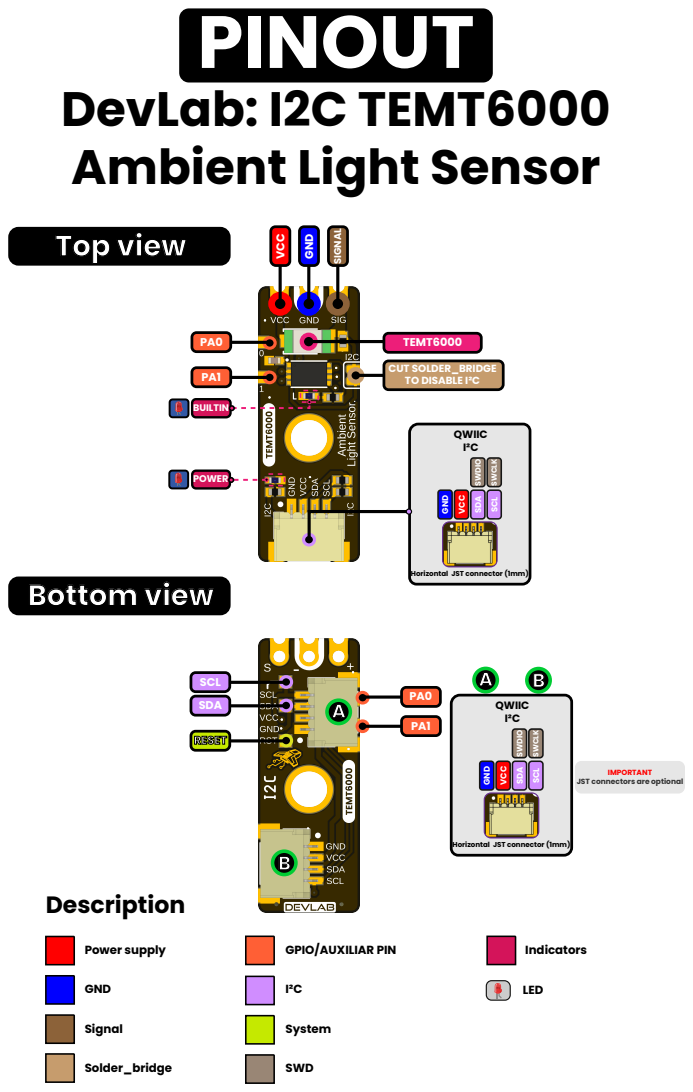
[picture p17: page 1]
Bottom view; POWER; VCC; GND; SCL SDA; RESET; CUT SOLDER_BRIDGE TO DISABLE I²C; TEMT6000; SIGNAL; BUILTIN; SDA; SCL; SWDIO; SWCLK; QWIIC I²C; Power supply; Signal; Solder_bridge; I²C; System; SWD; Indicators; Description; LED

Ambient Light Sensor
Top view

Horizontal JST connector (1mm) GND VCC SDA

IMPORTANT
JST connectors are optional

Horizontal JST connector (1mm)

GPIO/AUXILIAR PIN

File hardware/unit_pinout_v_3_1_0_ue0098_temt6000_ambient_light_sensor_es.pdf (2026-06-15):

# PINOUT

# DevLab: I2C TEMT6000

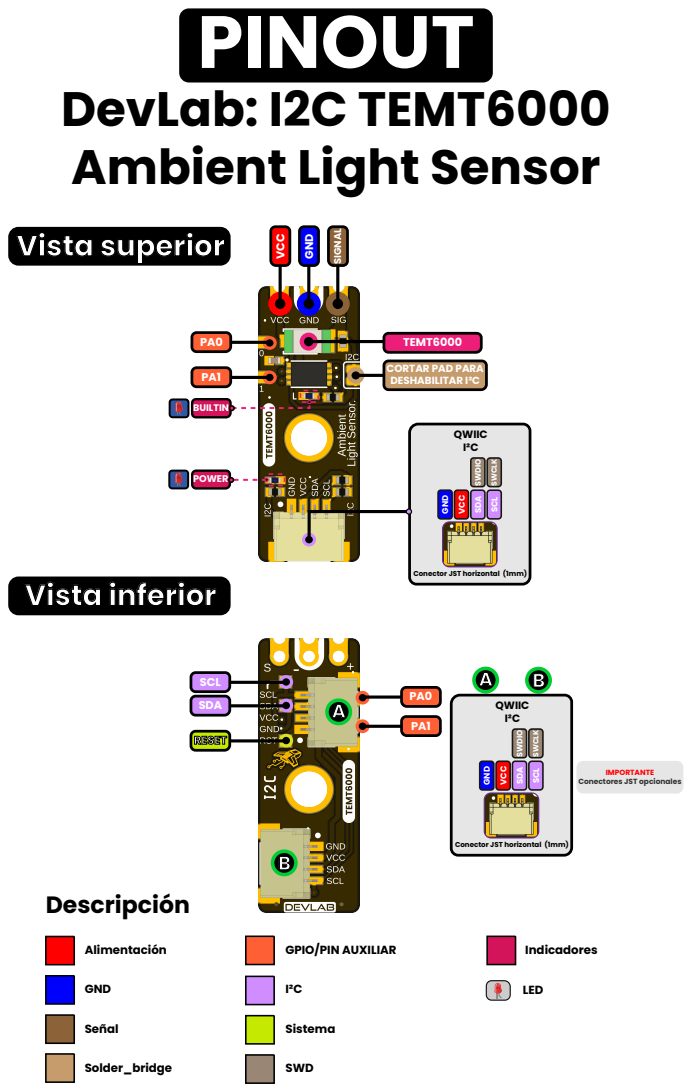
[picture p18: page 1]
Vista inferior; POWER; VCC; GND; SCL SDA; RESET; SIGNAL; BUILTIN; SDA; SCL; SWDIO; SWCLK; QWIIC I²C; Alimentación; Señal; Solder_bridge; I²C; Sistema; SWD; Indicadores; Descripción; LED

Ambient Light Sensor
Vista superior

TEMT6000
CORTAR PAD PARA
DESHABILITAR I²C

Conector JST horizontal (1mm) GND VCC SDA

IMPORTANTE
Conectores JST opcionales

Conector JST horizontal (1mm)

GPIO/PIN AUXILIAR

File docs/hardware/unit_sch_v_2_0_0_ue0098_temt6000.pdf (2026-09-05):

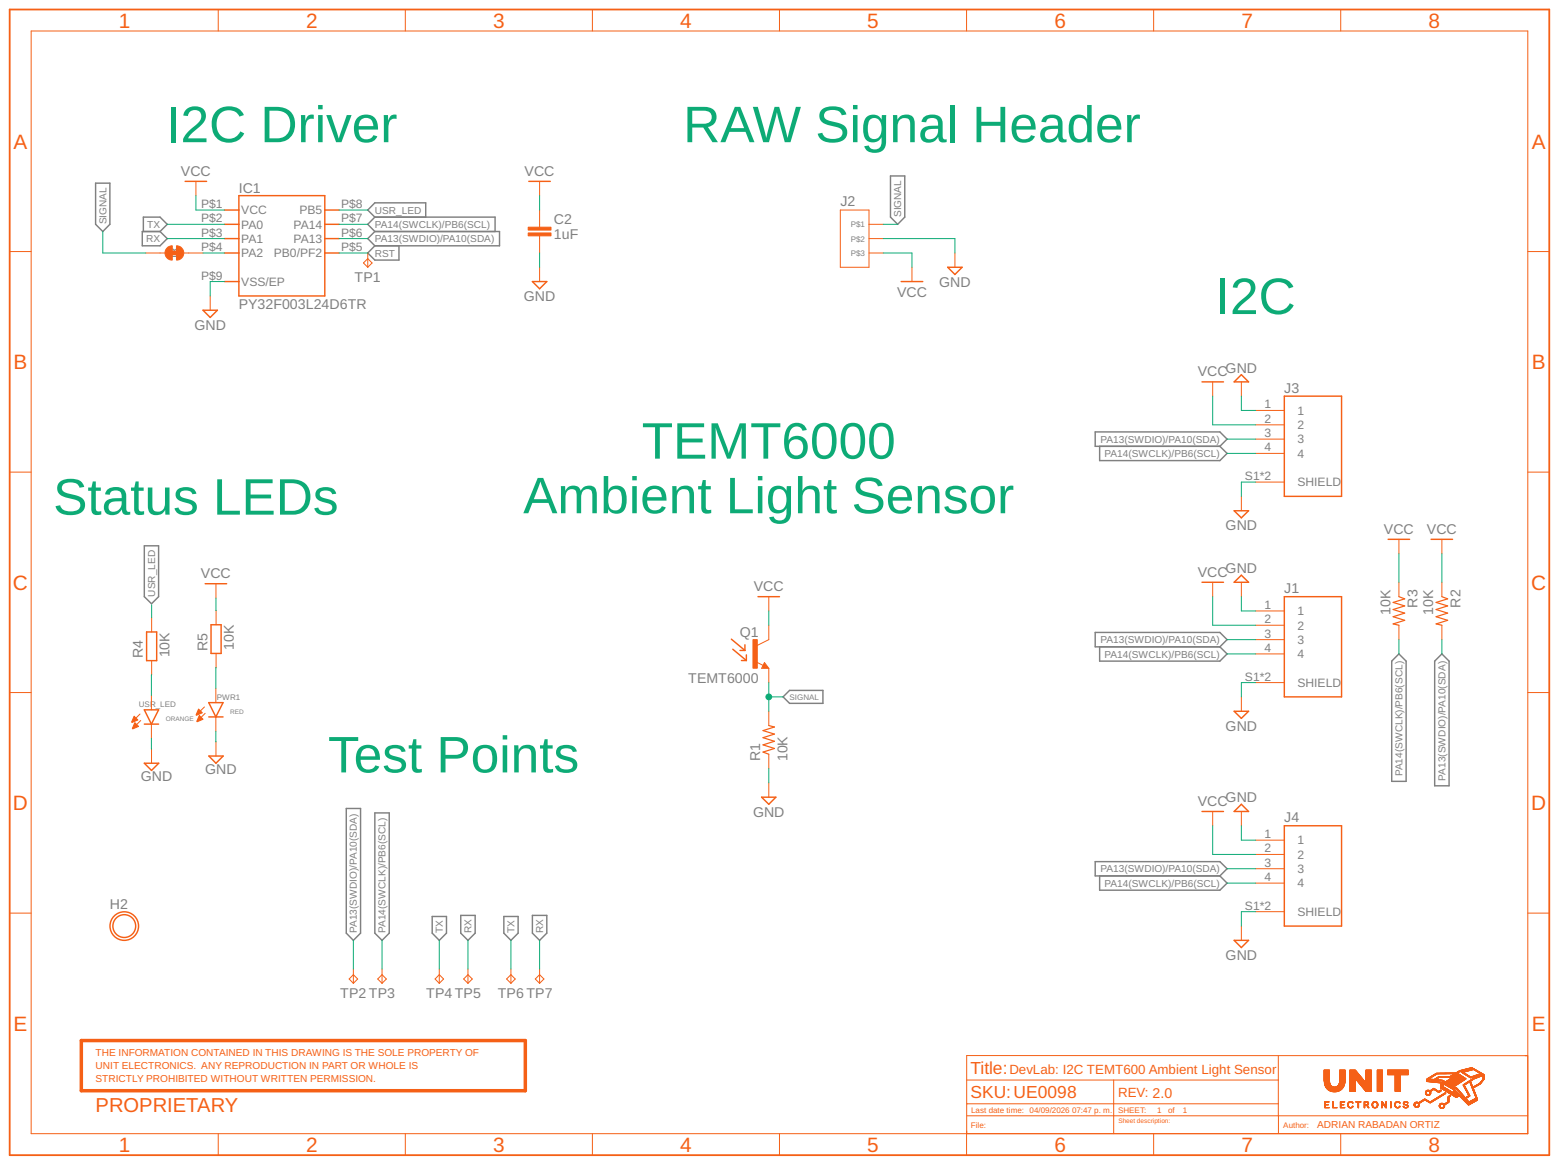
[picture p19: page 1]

PA14(SWCLK)/PB6(SCL) PA13(SWDIO)/PA10(SDA)

THE INFORMATION CONTAINED IN THIS DRAWING IS THE SOLE PROPERTY OF UNIT ELECTRONICS. ANY REPRODUCTION IN PART OR WHOLE IS

ADRIAN RABADAN ORTIZ DevLab: I2C TEMT600 Ambient Light Sensor
SKU:

STRICTLY PROHIBITED WITHOUT WRITTEN PERMISSION. PROPRIETARY

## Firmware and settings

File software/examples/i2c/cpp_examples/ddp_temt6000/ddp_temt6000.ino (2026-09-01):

#include <Arduino.h>
#include <Wire.h>
#include <DevLabDDP.h>

namespace {

constexpr uint8_t FACTORY_I2C_ADDRESS = 0x20U;
constexpr uint32_t I2C_CLOCK_HZ = 400000UL;
#if defined(ARDUINO_ARCH_ESP32)
constexpr uint8_t I2C_SDA_PIN = 6U;
constexpr uint8_t I2C_SCL_PIN = 7U;
#endif
constexpr uint16_t DDP_ADC_MAX = 4095U;
constexpr uint32_t CURRENT_CAPABILITIES = 0x000001B9UL;
constexpr uint8_t EXPECTED_ADC_AVERAGING_ACK = 0x0CU;
// Command-specific packed-ACK low nibbles; 0x01 means RELAY_ON accepted here.
constexpr uint8_t EXPECTED_RELAY_OFF_ACK = 0x00U;
constexpr uint8_t EXPECTED_RELAY_ON_ACK = 0x01U;
constexpr uint8_t BUILTIN_BLINK_COUNT = 3U;

// Set to 0x08..0x77 to request a persistent address change; 0 disables it.
constexpr uint8_t REQUESTED_I2C_ADDRESS = 0U;
// Set to 1, 4, 8, 16, or 24; 0 only reports the current persistent value.
constexpr uint8_t REQUESTED_ADC_AVERAGING = 0U;

DevLabDDP::Master temt6000(Wire, DevLabDDP::DEVICE_TEMT6000);
DevLabDDP::DeviceInfo deviceInfo;
uint8_t deviceAddress = 0U;
uint8_t averagingSamples = 1U;

bool ackLowNibbleIs(uint8_t response, uint8_t expected) {
  return (response & 0x0FU) == expected;
}

bool identifyAt(uint8_t address) {
  DevLabDDP::DeviceInfo candidate;
  if (!temt6000.matchesExpectedDevice(address, &candidate)) return false;
  if ((candidate.capabilities & DDP_CAP_ANALOG_INPUT) == 0U) return false;

  deviceAddress = address;
  deviceInfo = candidate;
  DevLabDDP::printDeviceInfo(
      Serial, deviceAddress, deviceInfo, DevLabDDP::DEVICE_TEMT6000);
  if (deviceInfo.capabilities != CURRENT_CAPABILITIES) {
    Serial.println("Notice: capabilities differ from firmware 1.0 profile.");
  }
  return true;
}

bool discoverTemt6000() {
  if (identifyAt(FACTORY_I2C_ADDRESS)) return true;
  for (uint8_t address = 0x08U; address <= 0x77U; ++address) {
    if (address != FACTORY_I2C_ADDRESS && identifyAt(address)) return true;
  }
  return false;
}

bool readRaw(uint16_t &value) {
  uint8_t bytes[2];
  if (!temt6000.readCommand(
          deviceAddress, CMD_READ_ADC0, bytes, sizeof(bytes), 5U)) {
    return false;
  }
  if ((bytes[1] & 0xF0U) != 0U) return false;
  value = static_cast<uint16_t>(bytes[0]) |
          (static_cast<uint16_t>(bytes[1]) << 8);
  return value <= DDP_ADC_MAX;
}

bool getAveraging(uint8_t &samples) {
  if (!temt6000.readCommand(
          deviceAddress, CMD_GET_ADC_AVERAGING, &samples, 1U, 5U)) {
    return false;
  }
  return samples == 1U || samples == 4U || samples == 8U ||
         samples == 16U || samples == 24U;
}

bool setAveraging(uint8_t samples) {
  if (samples != 1U && samples != 4U && samples != 8U &&
      samples != 16U && samples != 24U) {
    return false;
  }

  uint8_t current = 0U;
  if (!getAveraging(current)) return false;
  if (current == samples) {
    averagingSamples = current;
    return true;
  }

  uint8_t ack = 0U;
  if (!temt6000.readCommand(
          deviceAddress, CMD_SET_ADC_AVERAGING, &ack, 1U, 5U) ||
      !ackLowNibbleIs(ack, EXPECTED_ADC_AVERAGING_ACK) ||
      !temt6000.writeByte(deviceAddress, samples)) {
    return false;
  }

  delay(25U);
  if (Wire.requestFrom(deviceAddress, static_cast<uint8_t>(1U)) != 1U ||
      !ackLowNibbleIs(Wire.read(), EXPECTED_ADC_AVERAGING_ACK)) {
    return false;
  }

  averagingSamples = samples;
  delay(static_cast<uint32_t>(samples) * 20UL);
  return true;
}

void reportAndOptionallyChangeAddress() {
  uint8_t reportedAddress = 0U;
  if (temt6000.getI2cAddress(deviceAddress, reportedAddress)) {
    Serial.print("Active 7-bit address: 0x");
    if (reportedAddress < 0x10U) Serial.print('0');
    Serial.println(reportedAddress, HEX);
  }

  if (REQUESTED_I2C_ADDRESS == 0U || REQUESTED_I2C_ADDRESS == deviceAddress) {
    return;
  }
  if (!temt6000.setI2cAddress(deviceAddress, REQUESTED_I2C_ADDRESS)) {
    Serial.println("Address change failed; target may be occupied.");
    return;
  }

  deviceAddress = REQUESTED_I2C_ADDRESS;
  if (!identifyAt(deviceAddress)) {
    Serial.println("Device ID 0x0102 not verified at the new address.");
    deviceAddress = 0U;
  } else {
    Serial.println("Persistent address changed and identity verified.");
  }
}

bool actuatorCommand(uint8_t command, uint8_t expectedLowNibble) {
  uint8_t ack = 0U;
  return temt6000.readCommand(deviceAddress, command, &ack, 1U, 5U) &&
         ackLowNibbleIs(ack, expectedLowNibble);
}

void blinkBuiltin() {
  if ((deviceInfo.capabilities & DDP_CAP_RELAY) == 0U) return;
  for (uint8_t cycle = 0U; cycle < BUILTIN_BLINK_COUNT; ++cycle) {
    if (!actuatorCommand(CMD_RELAY_ON, EXPECTED_RELAY_ON_ACK)) return;
    delay(150U);
    if (!actuatorCommand(CMD_RELAY_OFF, EXPECTED_RELAY_OFF_ACK)) return;
    delay(150U);
  }
  Serial.println("BUILTIN blink complete (relay-compatible PB5 commands).");
}

void configureAveraging() {
  if (!getAveraging(averagingSamples)) {
    Serial.println("Could not read ADC averaging configuration.");
    return;
  }

  if (REQUESTED_ADC_AVERAGING != 0U &&
      !setAveraging(REQUESTED_ADC_AVERAGING)) {
    Serial.println("ADC averaging change failed.");
    return;
  }

  Serial.print("Device ADC averaging: ");
  Serial.print(averagingSamples);
  Serial.println(" sample(s)");
}

}  // namespace

void setup() {
  Serial.begin(115200);
#if defined(ARDUINO_ARCH_ESP32)
  Wire.begin(I2C_SDA_PIN, I2C_SCL_PIN);
#else
  Wire.begin();
#endif
  Wire.setClock(I2C_CLOCK_HZ);

  Serial.println("UNIT ATOM TEMT6000 — DDP v1.0");
  if (!discoverTemt6000()) {
    Serial.println("No compatible TEMT6000 DDP device found.");
    return;
  }

  reportAndOptionallyChangeAddress();
  if (deviceAddress == 0U) return;
  configureAveraging();
  blinkBuiltin();
}

void loop() {
  if (deviceAddress == 0U && !discoverTemt6000()) {
    delay(2000U);
    return;
  }

  uint16_t raw = 0U;
  if (readRaw(raw)) {
    Serial.print("ADC0/TEMT6000 raw (device average ");
    Serial.print(averagingSamples);
    Serial.print("): ");
    Serial.print(raw);
    Serial.println(" / 4095");
  } else {
    Serial.println("Read failed; rediscovering device.");
    deviceAddress = 0U;
  }

  delay(100U);
}

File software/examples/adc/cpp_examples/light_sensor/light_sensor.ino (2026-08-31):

#include <Arduino.h>

// Connect this pin to the V0.3.1 board's direct SIG contact.
const uint8_t SENSOR_PIN = A0;

#if defined(ARDUINO_ARCH_AVR)
const uint8_t ADC_BITS = 10;
#else
const uint8_t ADC_BITS = 12;
#endif

// Set this to the ADC's actual full-scale voltage.
const float ADC_FULL_SCALE_V = 3.3f;
const uint16_t SAMPLE_COUNT = 16;
const uint32_t ADC_MAX = (1UL << ADC_BITS) - 1UL;

void setup() {
  Serial.begin(115200);

#if defined(ARDUINO_ARCH_ESP32) || defined(ARDUINO_ARCH_RP2040)
  analogReadResolution(ADC_BITS);
#endif

  pinMode(SENSOR_PIN, INPUT);
  Serial.println("UNIT ATOM TEMT6000 direct analog SIG");
  Serial.println("V0.3.1 transfer and lux calibration are not yet specified.");
}

void loop() {
  uint32_t sum = 0;
  for (uint16_t i = 0; i < SAMPLE_COUNT; ++i) {
    sum += analogRead(SENSOR_PIN);
    delay(2);
  }

  const float raw = static_cast<float>(sum) / SAMPLE_COUNT;
  const float voltage = raw * ADC_FULL_SCALE_V / ADC_MAX;

  Serial.print("Raw: ");
  Serial.print(raw, 1);
  Serial.print("  Voltage: ");
  Serial.print(voltage, 3);
  Serial.println(" V");

  delay(500);
}

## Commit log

2025-12-02 Add TEMT6000 ambient light sensor datasheet v1.0.0
2025-12-02 docs(Readme): Update URLs for datasheet, getting started, schematics and pinout
2026-08-31 docs: use x7 voltage range without asserting suffix
2026-09-05 docs: update UE0098 documentation for new I2C architecture
    [unit_3d_ue0098_v_2_0_0_temt6000.f3d, unit_3d_ue0098_v_2_0_0_temt6000.step]
2026-09-07 fix:delete white background of the sensor image
2026-09-07 docs: add schematic image and remove duplicate views
2026-09-09 docs: clarify board layout and ratings
2026-09-18 docs(chapter-4): update sections 4.5 Auxiliary and Factory Service Functions and 4.6 Indicators and I2C Bridge
2026-09-18 docs(chapter-5): update section 5.3 with I2C voltage compatibility note
